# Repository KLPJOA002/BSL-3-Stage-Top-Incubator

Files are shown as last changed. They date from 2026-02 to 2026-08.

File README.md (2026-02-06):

# **Feasibility Study Around Designing a BSL-3 Compatible Stage Top Bio Containment System**
---
This repository contains the information relating to the investigation of commercial stage top incubation systems in order to determine the feasibility of designing a custom incubator system that provides the necesary environmental control and containment capibilities that allow it to be utilised within a BSL-3 laboratory.
This project extends to provide some conceptual containment designs that could be utiliesd for a prototpye capable of basic temperature control.

---
**Change Log:**
V1.0: 
1.  Chamber uses holes for bolts, base has hexagonal recesses for sitting the nut flush.
2.  Lid and Base use outwards facing notches for the insertion of viewing/illumination plates (Glass or aluminium).
3.  Base has a simple groove for an o-ring.

V2.0:
1.  Viewing/illumination plates notches moved to inside of chamber for better pressure sealing.
2.  Plate on base has been removed to reduce optical obstructions between objective and Multi-Well Plate.
3.  Multi-Well base used to seal the chamber. (Done with assumption of flat base)
4.  O-Ring Grooves for the lid designed to fit in V shaped groove in base, Oring sits in Lid.
5.  All O-ring sketches and extrusions made with parametric modeling.

V2.1: 
1.  Multi-Well model updated to include base frame (no longer flat bottom)
2.  Base seal with Multi-Well changed so that Multi-Well fram sits inside groove which will have gasket for seal.

V3.0:
1.  All corners are rounded for consideration with subtractive manufacturing.
2.  Inner chamber expanded for more internal space
3.  Size of chamber reduced.

V3.1:
1.  Minor Tweaks to dimensions

V3.2:
1.  Minor Tweaks to dimensions
   
V3.3:
1.  Inner chamber expanded furthur.
2.  V shape groove in base expanded for accomodation with 0.4mm 3D printer nozel
3.  Stand-offs added to lid to press the Multi-Well plate into the base.
4.  Holes for screws modified to allow for a hex socket screw with a head.

V3.4:
1.  Screws changed to be 7991 - Hexagon Socket Countersunk Screws (M4x10).
2.  Base screw hole modified to fit an insert for screw.

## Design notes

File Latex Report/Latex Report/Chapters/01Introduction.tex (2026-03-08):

% ----------------------------------------------------
% Introduction
% ----------------------------------------------------
\documentclass[class=report,11pt,crop=false]{standalone}
\input{../Style/ChapterStyle.tex}
\begin{document}
% ----------------------------------------------------
\chapter{Introduction} \label{ch:introduction}
\vspace{-1cm}
% ----------------------------------------------------

\section{Background and Summary}
Long term Live-Cell imaging is a very useful research tool when determining long term behavior of cell cultures in various situations. Commercial solutions are unable to provide adequate containment for the use within a Bio-Safety Level 3 (BSL-3) and often require the use of a separate containment enclosure, which introduces additional costs and complexity.

%This project focuses on the conceptual design of a low-cost Stage-Top Incubator that is capable of being utilized within a BSL-3 laboratory, without the requirement for additional containment. The primary focus with this project is specific suitability with Mycobacterium tuberculosis, however does consider other microbe requirements

This project focuses on the conceptual design of a bio-containment chamber which can be used within a BSL-3 lab to provide adequate containment for the long term observation of bacterial cultures. The main objective of this project is to allow long term observation of Mycobacterium tuberculosis (M. tb) grown in a multi-well plate.

This project is intended to provide an initial report on the feasibility of partaking in a further project to provide a complete incubation system for cell growth and observation.  

% =====================================================
\section{Scope and Limitations}
This project scope is limited to the following:
\begin{itemize}
	\item Preliminary Research
	\item Bio-Containment
	\item Compatibility with Multi-Well microtiter plates
	\item Primary containment of Mycobacterium tuberculosis (M. tb)
\end{itemize}

This project is limited to compatibility with a BSL-3 Lab and does not consider higher containment requirements. The chamber does not include any environmental control aspects and is limited to providing containment. The initial design is limited to compatibility with a Greiner 96 well microtiter plate. The use case of this project is limited to consider the requirements of M. tb

% =====================================================
\section{GitHub Link}
 The project documentation and container model files can be found at \url{https://github.com/KLPJOA002/BSL-3-Stage-Top-Incubator}
% ----------------------------------------------------
\ifstandalone
\bibliography{../Bibliography/References.bib}
\fi
\end{document}
% ----------------------------------------------------

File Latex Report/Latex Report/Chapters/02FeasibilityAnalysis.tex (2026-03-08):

% ----------------------------------------------------
% Requirements Analysis
% ----------------------------------------------------
\documentclass[class=report,11pt,crop=false]{standalone}
\input{../Style/ChapterStyle.tex}
\begin{document}
% ----------------------------------------------------
\chapter{Specification Analysis} \label{ch:FeasibAnalysis}
\vspace{-1cm}
% ----------------------------------------------------
% =====================================================
\section{Commercial Assessment}
The commercial solutions from Zeis/Pecon, Ibidi, Tokai-Hit and Okolab are assessed for their primary method of operation as well as the environmental control specifications provided by each product.

\subsection{Zeis/Pecon}
The incubation system provided by Zeis/Pecon utilises four modules for the control of the four major environmental conditions. A temperature unit for thermal control, a CO2 unit for CO2 concentration control, an O2 unit for O2 concentration control and a humidifying bottle for humidity control.

The heating unit monitors and controls the temperature of the culture sample through heating of the incubation chamber, gas airflow and humidifying bottle.

The CO2 unit monitors and controls the concentration of CO2 being pumped into the incubation chamber by controlling the release of pure CO2 gas into the internal mixing chamber.

The O2 unit monitors and controls the concentration of O2 being pumped into the incubation chamber by controlling the release of Pure N2 gas into the circulating gas in order to displace the O2 present. Thus can only achieve hypoxia conditions.

The humidifying unit operates by bubbling the gas mixture through heated water to achieve a close to 100\% RH ro prevent the drying of the culture media.

The Zeis/Pecon incubation system as a whole has the specifications shown in \autoref{tab:Zeis/Pecon_Specs}.

\begin{table}[H]
	\centering
	\begin{tabularx}{\textwidth}{|X|X|}
		\hline
		\textbf{Temperature Control Range} & Ambient - 60\degree C (Recommended max 45\degree C)                                                             \\ \hline
		\textbf{Control Accuracy}          & \textpm0.15\%                                                                                        \\ \hline
		\textbf{Control Resolution}        & \begin{tabular}[c]{@{}l@{}}Internal Loop: 0.01\degree C\\ User Parameter: 0.1\degree C\end{tabular}             \\ \hline
		\textbf{CO2 Control Range}         & 0.0 - 8.0 vol\% (8.1-10 vol\% with Uncepecified Reduced Accuracy)                             \\ \hline
		\textbf{Control Accuracy}          & \textpm2 vol\%                                                                                       \\ \hline
		\textbf{Control Resolution}        & \begin{tabular}[c]{@{}l@{}}Internal Loop: 0.01 vol\%\\ User Parameter: 0.1 vol\%\end{tabular} \\ \hline
		\textbf{O2 Control Range}          & 0.0 - 21.0 vol\%                                                                              \\ \hline
		\textbf{Control Accuracy}          & \textpm0.05 vol\%                                                                                    \\ \hline
		\textbf{Control Resolution}        & \begin{tabular}[c]{@{}l@{}}Internal Loop: 0.01 vol\%\\ User Parameter: 0.1 vol\%\end{tabular} \\ \hline
		\textbf{Operation}                 & PC or Suitable Microscope required                                                            \\ \hline
		\textbf{Compatibility}             & Petri-Dishes, Chambers, Chamber Plates, Chamber Slides, Multi-Well Plates                     \\ \hline
	\end{tabularx}
	\caption{Specifications for Zeis/Pecon Incubation System \cite{peconPeconZeisTempModule}, \cite{peconPeconZeisCO2}, \cite{peconPeconZeisO2}, \cite{peconPeconZeisHeating}}
	\label{tab:Zeis/Pecon_Specs}
\end{table}
\subsection{ibidi}
The incubation system provided by Ibidi utilises three modules to maintain the environmental conditions within in incubation chamber. A temperature unit for thermal control, a CO2/O2 unit for CO2 and O2 concentration control, and a humidifying column for humidity control.

The heating unit monitors and controls the temperature of the culture sample through heating of the incubation chamber.

The CO2/O2 unit monitors and controls the concentration of both CO2 and O2 being pumped into the incubation chamber by controlling the release of pure CO2 and N2 into the gas mixture. The release of N2 displaces oxygen present in the air and so the system is only capable of producing hypoxia conditions. The CO2/O2 unit is also responsible for the heating of the gas mixture as well as the heating of the humidifying column and gas tube.

The humidification control system works by controlling the mix of dry gas with humidified gas which is obtained through bubbling the dry gas flow through heated distilled water.

The Ibidi incubation system as a whole has the specifications shown in \autoref*{tab:Ibidi_Specs}.

\begin{table}[H]
	\centering
	\begin{tabularx}{\textwidth}{|X|X|}
		\hline
		\textbf{Temperature Control Range} & Ambient + 5\degree C - 50\degree C                                \\ \hline
		\textbf{Control Accuracy}          & \textpm 0.2\degree C with \textpm 0.5\degree C uniformity                         \\ \hline
		\textbf{Control Resolution}        & User Parameter: 0.1\degree C                             \\ \hline
		\textbf{CO2 Control Range}         & 0.0 - 15.0 vol\%                                \\ \hline
		\textbf{Control Accuracy}          & \textpm 0.2 vol\% + 3\% of Reading                      \\ \hline
		\textbf{Control Resolution}        & User Parameter: 0.1 vol\%                       \\ \hline
		\textbf{O2 Control Range}          & 0.5 - 21.0 vol\%                                \\ \hline
		\textbf{Control Accuracy}          & \textpm 0.2 vol\% (typical), \textpm 0.7 vol\% (max)            \\ \hline
		\textbf{Control Resolution}        & User Parameter: 0.1 vol\%                       \\ \hline
		\textbf{Humidity Control Range}    & Supply RH - 99\% RH                             \\ \hline
		\textbf{Sensor Accuracy}           & \textpm 2.5\%                                           \\ \hline
		\textbf{Control Resolution}        & 0.1\%                                           \\ \hline
		\textbf{Operation}                 & On Device Controls or Connected PC              \\ \hline
		\textbf{Compatibility}             & Petri-Dishes, Chamber Slides, Multi-Well Plates \\ \hline
	\end{tabularx}
	\caption{Specifications for Ibidi Incubation System \cite{ibidiIbidiHeatingSystem}, \cite{ibidiIbidiGasIncubation}}
	\label{tab:Ibidi_Specs}
\end{table}

\subsection{Tokai Hit}
The incubation system provided by Tokai hit utilises one or two modules to maintain the environmental conditions within the incubation chamber, depending on the parameters that are desired to be controlled. The STXG/STXF module is capable of regulating both temperature conditions and CO2 gas concentration. An additional unit, STX-CO2O2, can be connected to the system to override the gas mixture control, and provide control for CO2 and O2 concentration.

The STXG/STXF unit monitors and controls the temperature of the culture sample through heating of the incubation chamber. Additionally this unit is capable of regulating the concentration of CO2 being pumped into the incubation chamber. The STXG model can regulate the CO2 concentration by controlling the release of pure CO2 into the gas mixture, whereas the STXF module requires a pre-mixed pressurised air supply with 5\% CO2.

O2 concentration can be achieved using a separate optional module which provides full gas concentration control.

Humidity in the incubation chamber is controlled through a heated water bath that is situated inside the chamber, and so forces a constant high relative humidity.

The specifications for the STXG and STX-CO2O2 incubation system is shown in \autoref{tab:TokaiHit_Specs}.  
\begin{table}[H]
	\centering
	\begin{tabularx}{\textwidth}{|X|X|}
		\hline
		\textbf{Temperature Control Range} & Ambient +5\degree C - 65\degree C         \\ \hline
		\textbf{Control Accuracy}          & \textpm 0.3\degree C at heater surface    \\ \hline
		\textbf{Control Resolution}        & User Parameter 0.1\degree C               \\ \hline
		\textbf{CO2 Control Range}         & 5\% vol - 20\% vol                        \\ \hline
		\textbf{Control Accuracy}          & \textpm 0.1\% vol                         \\ \hline
		\textbf{Control Resolution}        & User Parameter 0.1\% vol                  \\ \hline
		\textbf{O2 Control Range}          & 0.1\% vol - 18\% vol                      \\ \hline
		\textbf{Control Accuracy}          & ---                                       \\ \hline
		\textbf{Control Resolution}        & ---                                       \\ \hline
		\textbf{Operation}                 & On Device or Connected PC                 \\ \hline
		\textbf{Compatibility}             & Petri-Dishes, Chamber Slides, Multi-Well Plates\\ \hline
	\end{tabularx}
	\caption{Specifications for the Tokai Hit Incubation System \cite{tokaihitSTXSeriesInstruction}}
	\label{tab:TokaiHit_Specs}
\end{table}

\subsection{OkoLab}
The incubation system provided by OkoLab utilises three modules to maintain the environmental conditions. A temperature unit for thermal control, a gas unit for CO2 and O2 concentration control and a humidifying bottle. 

The heating unit monitors and controls the temperature of the culture sample through heating of the incubation chamber.

The CO2/O2 unit monitors and controls the concentration of both CO2 and O2 being pumped into the incubation chamber. The gas module is capable of working with a mix of concentrated O2, concentrated CO2, and concentrated N2 to obtain a complete control of the gas mixture being passed into the incubation chamber. Alternatively, the unit can operate with a supply of pressurised air, concentrated N2 and concentrated CO2 to get less complete atmospheric control.

Humidity control is obtained by bubbling the gas mixture through heated water to increase the relative humidity.

The specifications for the OkoLab incubation system is shown in \autoref{tab:OkoLabs_Specs}

\begin{table}[H]
	\centering
	\begin{tabularx}{\textwidth}{|X|X|}
		\hline
		\textbf{Temperature Control Range} & Ambient +3\degree C - 60\degree C                                               \\ \hline
		\textbf{Control Accuracy}          & \textpm 0.1 for sample feedback, \textpm 0.3 for chamber feedback             \\ \hline
		\textbf{Control Resolution}        & User Parameter 0.1                                            \\ \hline
		\textbf{CO2 Control Range}         & 0\% vol - 20\% vol                                            \\ \hline
		\textbf{Control Accuracy}          & \textpm 0.2\% vol at 5\% vol                                          \\ \hline
		\textbf{Control Resolution}        & User Parameter 0.1\% vol                                      \\ \hline
		\textbf{O2 Control Range}          & 0\% vol - 95\% vol (using Pure O2 source, otherwise 20\% max) \\ \hline
		\textbf{Control Accuracy}          & \textpm 0.2\% at 5\% vol                                              \\ \hline
		\textbf{Control Resolution}        & User Parameter 0.1\% vol                                      \\ \hline
		\textbf{Humidity Control Range}    & 26\% RH - 95\% RH at 50                                       \\ \hline
		\textbf{Control Accuracy}          & \textpm 1\%                                                           \\ \hline
		\textbf{Control Resolution}        & User Parameter 1\%                                            \\ \hline
	\end{tabularx} 
	\caption{Specifications for the OkoLab Incubation System}
	\label{tab:OkoLabs_Specs}
\end{table}
% =====================================================
\section{Requirements}
The eventual goal of this project is the development of a stage top incubator that can be used for long term observations of M. tb within a BSL-3 without the requirement of a large external incubation and containment chamber.

However this report focuses on determining the feasibility of undertaking this project, and so has a reduced set of requirements aimed at scoping the fundamental aspects that would be required to understand the project scope.
Therefore the requirements for this project include the following:
\begin{itemize}
	\item Containment of Mycobacterium tuberculosis (M. tb)
	\item Compatibility with low magnification microscope stage
	\item Compatibility with a BSL-3 laboratory
	\item Compatibility with a 96-well culture vessel
\end{itemize}

This project focuses on the main aspect of bio-containment within a BSL-3 lab and how that can be achieved with a format that is compatible with the growth vessels and microscopy standards that are utilised for this kind of experiment.
\begin{comment}

\begin{table}[h]
    \centering
    \caption{User and functional requirements of the power subsystem.}    \label{tab:requirements}
    \begin{tabular}{|c|l|}
        \hline
        \textbf{ Requirement ID} & \textbf{Description} \\
        \hline
         UR01 & \\
         \hline
         FR01 & \\
         \hline
         &  \\
         \hline
         &  \\
         \hline
    \end{tabular}
\end{table}
\end{comment}

% =====================================================
\section{Specifications}

The commercial solutions were assessed to obtain an understanding of specifications the stage-top incubator project would need to meet in order to achieve a incubation system that would provide suitable conditions required for this type of long term imaging with cell cultures.

\autoref{tab:Derived_Specs} shows the list of specifications that were decided on based off the specifications for the commercial solutions shown above. These specifications fall within those provided by commercial solutions and should facilitate the incubation of most cell cultures.

\begin{table}[]
	\centering
	\begin{tabular}{|l|l|}
		\hline
		\textbf{Temperature Control Range} & Ambient - 55         \\ \hline
		\textbf{Temperature Accuracy}      & 0.2                  \\ \hline
		\textbf{Temperature Resolution}    & 0.1                  \\ \hlineB{5} 
		\textbf{CO2 Control Range}         & 0\% vol - 15\% vol   \\ \hline 
		\textbf{CO2 Control Accuracy}      & 0.1\% vol            \\ \hline
		\textbf{CO2 Control Resolution}    & 0.1\% vol            \\ \hlineB{5}
		\textbf{O2 Control Range}          & 0.5\% vol - 20\% vol \\ \hline
		\textbf{O2 Control Accuracy}       & 0.1\% vol            \\ \hline
		\textbf{O2 Control Resolution}     & 0.1\% vol            \\ \hlineB{5}
		\textbf{Humidity Control Range}    & 90\% RH - 99\%RH     \\ \hline
		\textbf{Humidity Control Accuracy} & ---                  \\ \hline
		\textbf{Humidity Control Range}    & ---                  \\ \hline
	\end{tabular}
	\caption{Derived Specifications for the Continuation of this Project.}
	\label{tab:Derived_Specs}
\end{table}
\begin{comment}
\begin{table}[h]
    \centering
    \caption{Specifications of the sensing subsystem derived from the requirements in \autoref{tab:requirements}.}    \label{tab:specifications}
    \begin{tabular}{|c|l|}
        \hline
        \textbf{Specification ID} & \textbf{Description} \\
        \hline
         SP01 & User \\
         \hline
         &  \\
         \hline
         &  \\
         \hline
    \end{tabular}
\end{table}
\end{comment}
% =====================================================
%\section{Feasibility}
%discus whether undertaking this project is feasible. 
% The table given below is an example of how you can present your ATPs. You are welcome to change or adapt it to your need. The example given is not a valid ATP description.

\begin{comment}
\begin{table}[h]
  \begin{center}
    \caption{Subsystem acceptance tests}
    \label{tab:tests}
    \begin{tabular}{| >{\centering\arraybackslash}m{1cm} | m{4cm}| m{5cm}| m{5cm}|}
      \hline
      \textbf{ID} & \textbf{Description} & \textbf{Testing Procedure}& \textbf{Pass/Fail Criteria} \\   
      \hline
      AT01 & Powers on & \tabitem \newline\indent\tabitem & \\
      \hline
       &  &\tabitem \newline\indent\tabitem  & \\
      \hline 
    \end{tabular}
  \end{center}
\end{table}

\end{comment}

% ----------------------------------------------------
\ifstandalone
\bibliography{../Bibliography/References.bib}
\fi
\end{document}
% ----------------------------------------------------

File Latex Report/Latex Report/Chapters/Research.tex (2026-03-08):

% ----------------------------------------------------
% Research
% ----------------------------------------------------
\documentclass[class=report,11pt,crop=false]{standalone}
\input{../Style/ChapterStyle.tex}
\begin{document}
	% ----------------------------------------------------
	\chapter{Research} \label{ch:Research}
	\vspace{-1cm}
	% ----------------------------------------------------
	%The conceptual design began with assessing existing commercial products to identify the key environmental control specifications required for the incubator to function correctly. Additionally, this was useful in identifying why the commercial products are incompatible with a BSL-3 lab when used without a separate external biological containment mechanism.
	
	The design process began by researching existing commercial products that provide stage-top incubation. This allows for the assessment of these commercial solutions to identify the methods of operation and the specifications that would be required for the possible design of a complete incubation system. Further this identifies the shortfalls that prevent the use of these products within BSL-3 laboratories as bio-containment chambers.
	
	\section{Zeis/Pecon}
	The Zeis/Pecon stage top incubator utilities four modules to control the environmental conditions within the incubator stage. 
	
	The Pecon Temperature Module S\cite{peconPeconZeisTempModule} regulates the temperature of the incubator. It has four 8-pin connectors that are used for temperature control of heated components such as the Incubator lid, incubator base, microscope objective and humidifier device. The temperature module is the base module for the entire incubation system, providing electrical power and communications to all connected devices. It directly connects to the CO2 module to provide power, communication and makes a connection to the gas circulation system to heat the gas flow provided to the incubation chamber. The temperature module requires an external device such as a PC or compatible microscope for operation as it does not have any control panel. The module maintains culture temperature by monitoring and controlling the temperature of the incubator base, lid and optionally the microscope objective. The module is capable of controlling the culture temperature using thermal pre-sets, or by performing a pre-experiment calibration whereby an identical set-up is placed in the chamber with the included culture temperature sensor to tune the required chamber temperatures. 
	
	The Pecon CO2 Module S\cite{peconPeconZeisCO2} attaches to the temperature module for electrical power and communication, and provides CO2 concentration control to the airflow passed into the incubation chamber. The CO2 module circulates gas throughout all the connected units and mixes the gas before pumping the resultant mixture into the incubation chamber. The module contains a CO2 sensor which monitors the concentration of CO2 in the gas mixture, and controls the release of pure CO2 into the mixing chamber in order to maintain the desired CO2 concentration. Due to the method of operation, it requires a >95\% purity CO2 supply.
	
	The Pecon O2 Module S\cite{peconPeconZeisO2} attaches to the CO2 module for electrical power and communication. This module functions similarly to the CO2 module, however it regulates the concentration of O2 present in the gas mixture by controlling the release of a pure N2 supply into the air mixture to displace the O2 present. This method of O2 displacements means that the O2 module is only capable of providing hypoxia conditions by lowering O2 concentration. Due to the method of operation, it requires a >99\% purity N2 supply.
	
	%The Pecon Heating Device Humidity S\cite{pecon_peconzeis_nodate-3} connects in series with the airflow tube to the incubator stage. This module works by bubbling the airflow through heated sterile water in order to raise the relative humidity (RH) to approximately 100\%.
	
	Both the CO2 module and O2 module are supplied with a humidifying bottle which functions by bubbling the the gas airflow thorugh distilled water to raise the relative humidity (RH). The Pecon Heating Device Humidity S1\cite{peconPeconZeisHeating} is an optional module which connects to the Temperature module to heat the humidifying bottle to increase the RH and maintain adequete gas temperature provided to the incubation chamber
	
	The incubator stage includes a heated glass topped lid\cite{peconIncubatorS1Compact} and a heated insert which accepts mounts for the different culture vessels used in microscopy. The heated insert directly heats the culture medium through physical contact, and the heated lid provides radiative heating and condensation prevention by heating the glass panel directly. The insert supports perfusion experiments utilising two ports which allow tubes to be run to the culture.
	
	%The main reason why the Zeis/Pecon stage top incubator system is not suitable for long term imaging without an external containment enclosure is due to the method of gas flow through the incubator. The design of the Incubator stage is such that the inflowing gas mixture flows over the culture media and then exhausts passively through the opening on the bottom and through the sides. This means that the cell culture is not completely sealed inside the incubator which can result in contamination. The incubator lid and heated insert are not autoclabale and this reduces the sterilisation capibilities of the incubation chamber.
	
	\section{Ibidi}
	The Ibidi stage top incubator functions similarly to the Zeis/Pecon module, however it makes use of three modules to maintain environmental conditions.
	
	The Heating System Silver Line\cite{ibidiIbidiHeatingSystem} module regulates the temperature of the incubator. It makes use of 6 independent channels connected via 4 ports, two of which connect to two channels each. These channels are used to monitor and control the temperature of the components used in the system, such as the heated lid and heated plate. The module maintains culture temperature by monitoring and controlling the temperature of the heated lid, heated base and optionally the microscope objective. The module infers the culture temperature using pre-set temperatures, or by performing a calibration whereby an identical set-up is placed in the chamber with the included thermocouple to tune the required chamber settings to meet the desired culture temperature. The temperature module can be operated using the on device buttons and screen, or it can be connected to a PC for control using the free software. The temperature module does not heat the gas mixture.
	
	The Gas Incubation System\cite{ibidiIbidiGasIncubation} comes in two different models, the CO2 - Silver Line and the CO2/O2 - Silver Line. The difference between these two systems is the former is only capable of regulating CO2 concentration, where as the latter has the ability to regulate O2 concentration as well as CO2 concentration. The module has three gas inputs for pressurised air, CO2 and N2. The CO2 and N2 are fed into and mixed with the pressurised air to obtain a mixture with the desired CO2 and O2 concentrations. The module then heats the gas mixture before pumping it to the incubation chamber. If the CO2 only module is used, the N2 air input is still present on the device, however it is sealed internally and so the module is unable to regulate O2 concentration. Due to the method of using N2 to displace O2 in the mixture, this system is only capable of producing hypoxia environments. The gas incubator module has two output ports which are used in conjunction with the Humidifying column to mix the dry gas with humidified gas to obtain the desired relative humidity as shown in \autoref{fig:ibidiHumidityControlDiagram}. The gas incubation module has two electrical connections, one to control the heating of the humidifying column and gas line, and the second to connect to the humidity sensor present in the incubation chamber. The module can be operated using the on device buttons and screen, or it can be connected to a PC for control using the free software.
	
	The Humidifying column\cite{ibidiIbidiGasIncubation} works by bubbling the airflow through heated, distilled water to increase the relative humidity to approximately 100\% RH. This is then mixed with dry gas to obtain the desired \% RH.
	
	The Ibidi incubation chamber comes in two versions, one version supports culture mediums with Petri dishes and slides, the second version supports multi-well plates. The Petri dish/Slide version of the chamber supports perfusion experiments using two ports which allow tubes to be run to the culture. Both chambers directly heat the culture medium through physical contact and provide radiative heating and condensation prevention by heating the glass lid.

	\begin{figure}
		\centering
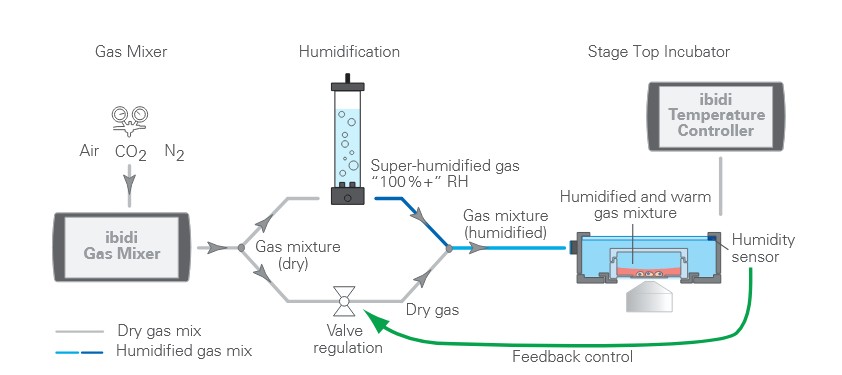
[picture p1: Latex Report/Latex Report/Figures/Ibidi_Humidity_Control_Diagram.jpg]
		
		\caption[Ibidi Chamber Gas Flow Diagram]{Diagram Showing the Humidity Control Mechanism Used by the Ibidi Gas Incubation System \cite{ibidiIbidiGasIncubation}}
		\label{fig:ibidiHumidityControlDiagram}
	\end{figure}
	
	\section{Tokai-Hit}
	The Tokai-Hit system functions similarly to the Pecon and Ibidi systems however it utilises a single module to regulate the environmental conditions for temperature and CO2. Humidity is controlled by a heated water bath inside the chamber, and O2 control is achieved by utilising an optional module which then overrides all gas control.
	
	The Tokai-Hit STXG/STXF\cite{tokaihitSTXSeriesInstruction} temperature and CO2 controller regulates both temperature and CO2 concentration in the incubation chamber. The controller utilises a single connector to control all component temperatures such as the Lid heater, bath heater, stage heater and optional microscope objective heater. The module can regulate thermal conditions of the culture using pre-set temperatures, however it can operate in feedback mode whereby a sensor directly monitors the temperature of the culture medium and automatically adjusts the component temperatures to meet the desired set point. The module can be operated using the built in touch screen or it can be connected to a PC for control using software.
	
	The STXG and STXF models both provide airflow to the incubation chamber, however the STXG model is capable of controlling the CO2 concentration by feeding supplied CO2 into the gas mixture until the desired concentration is reached, then pumps the mixture to the incubation chamber. The STXF model is unable to regulate CO2 concentration, and so requires a pre-mixed pressurised CO2/air.

	The incubator chamber uses a single design that is compatible with most major culture vessels including Petri dishes, slides and multi-well plates. This chamber supports perfusion experiments, drug administration and direct culture temperature measurement via access ports designed into the lid. The humidity inside the incubation chamber is maintained via a water bath that is present inside the chamber, and which is heated by the STXG/STXF module.
	
	The STXG/STXF modules can optionally be connected to a separate CO2/O2 unit which overrides the gas control mixture and allows for the optional control of O2 concentration.

	\section{OkoLab}
	The OkoLab utilises three modules to regulate environmental conditions within the incubation chamber
	
	The OkoLab H301-T-UNIT-BL-PLUS\cite{oko-labH301TUNITBLPLUS_Manual} unit is responsible for maintaining the thermal conditions within the chamber enclosure. It operates by monitoring and controlling the temperature of the chamber base, lid and optionally the microscope objective. This in turn heats the sample to the desired temperature. This heating unit is capable of sample temperature feedback utilising a thin thermocouple that can be placed in distilled water near the sample to obtain more accurate sample temperature control. Otherwise the unit is capable of using pre-sets/calibrations to infer sample temperature based on enclosure temperatures. The heating unit can be operated via a computer using available software or using optional touch screen accessory. The heating unit is capable of interfacing with the Oko-Lab Bold Line Gas Controllers. The temperature module supports a programmed temperature cycle mode where it cycles between set temperatures.

	The CO2-O2-UNIT-BL\cite{oko-labCO2O2UNITBL020_195_Manual} modules come in a variety of formats, differing in the O2 control ranges they support. The CO2-O2-UNIT-BL [0-20; 1-95] variant supports O2 concentration range from 1\% to 95\%. This model requires a pressurised supply of CO2, N2 and O2 to obtain the desired gas mixture, alternatively compressed air or an air pump can be connected to the N2 supply which limits the functionality to just CO2 concentration control. The CO2-O2 BL line all have the capability to directly interface with the Temperature unit to allow communication between the two units.
	
	The HM-ACTIVE\cite{oko-labHMACTIVE_Manual} operates by passing the gas mixture over heated water to increase the RH. The water temperature can be altered to control the RH of the out flowing gas. The humidity control unit is controlled by the gas mixture unit.
	
	The H301-K-FRAME\cite{oko-labH301KFRAME_User_Manual} uses a design that is compatible with most major culture vessels, each using a different sample holder. The chamber is also designed to work with various lids depending on the required application. The chamber supports perfusion experiments and microfluidic experiments. The chamber directly heats the culture medium through physical contact and provides radiative heating and condensation prevention by heating the glass lid

	\section{Shortfalls}
	
	\subsection{Containment}
	The commercial solutions provided by Zeis/Pecon, ibidi, Tokai Hit and OkoLab are all unable to operate independently, without an external containment chamber, within a BSL-3 laboratory due to a fundamental design choice present in all solutions. The Incubation chambers are designed to have an imperfect containment seal to allow the incoming gas flows to passively exhaust out the base and any gaps in the enclosure. This can be seen in the diagram shown in \autoref{fig:ibidigasflowdiagram} which is provided by ibidi.
	
	This means that the exhausting air is unfiltered and may be contaminated with the cells present during the experiment, which can lead to contamination of the surrounding workspace. For this reason, when working with potentially lethal pathogens, it is required that the incubator be placed within a larger containment vessel to ensure that contamination does not occur.
	
	\subsection{Disinfection and sterilisation}
	
	All equipment inside of a BSL-3 lab requires either sterilisation or disinfection depending on the equipment use or properties. Sterilisation is used to kill almost all micro cellular activity on an item and is rated on the Sterility Assurance Level (SAL) which indicates the probability of a single microbe surviving. Disinfection is used to kill enough micro cellular life to achieve a safe enough level required by the laboratory.
	Examples of sterilisation and disinfection techniques are as follows:
	
	\begin{itemize}
		\item Sodium hypochlorite(bleach), is useful as a broad spectrum disinfectant and is effective against bacterial spores\cite{BiologicalSafetyManual2021}, \cite{BiosafetyManualAppendixIDisinfectantsforBiohazardousMaterialsSOP}, \cite{barryBSL3LabDecontamination2025}. 
		
		\item hydrogen peroxide, which is a very effective sterilising chemical\cite{BiologicalSafetyManual2021} and is often used for sterilisation of tools, biological safety cabinets and laboratories\cite{grareEfficacyDryMist2008}.
		
		\item Quaternary Ammonium Compounds, which provides cost effective but low level disinfection\cite{BiologicalSafetyManual2021}, \cite{BiosafetyManualAppendixIDisinfectantsforBiohazardousMaterialsSOP}, \cite{barryBSL3LabDecontamination2025}.
		
		\item Alcohols, which offer an intermediary disinfection \cite{BiologicalSafetyManual2021}, however are ineffective against spores\cite{BiosafetyManualAppendixIDisinfectantsforBiohazardousMaterialsSOP}
		
		\item Autoclave, which provides extremely effective sterilization using a pressurized containment vessel filled with steam heated to approximately \(120^\circ\)C 
	\end{itemize}
	
	The aforementioned commercial solutions specify the use of concentrated  alcohol solutions such as ethanol or isopropanol, which are not suitable for adequate sterilisation of microbes which produce spores, such as Mycobacterium tuberculosis, which is the primary cell considered in this feasibility study.
	
	Furthermore the Tokai hit and Zeis/Pecon incubators specify that they are not compatible with autoclave sterilisation, whilst the Ibidi and OkoLab incubators do not specify any compatibility or incompatibility.
	\subsection{Key Takeaways}
	The discussed commercial solutions are incompatible with experiments that require stage top incubation for stand alone, long term, live cell imaging within a BSL-3 lab. This is because of the lack of adequate containment capabilities as well as the incompatibility with disinfection and sterilisation methods required by the microbes of interest.
	
	\begin{figure}
		\centering
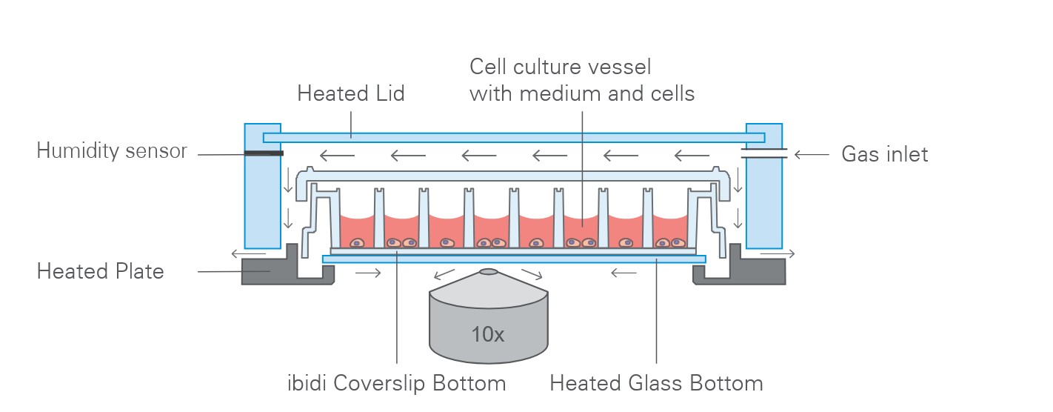
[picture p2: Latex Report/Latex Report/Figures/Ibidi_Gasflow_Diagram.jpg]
		
		\caption{Diagram Showing the Gas Flow within the ibidi Multi-Well Incubation Chamber}
		\label{fig:ibidigasflowdiagram}
	\end{figure}
	
	% ----------------------------------------------------
	\ifstandalone
	\bibliography{../Bibliography/References.bib}
	\fi
\end{document}
% ----------------------------------------------------

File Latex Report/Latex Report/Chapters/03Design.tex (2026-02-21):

% ----------------------------------------------------
% Subsystem Design
% ----------------------------------------------------
\documentclass[class=report,11pt,crop=false]{standalone}
\input{../Style/ChapterStyle.tex}
\begin{document}
% ----------------------------------------------------
\chapter{Conceptual Design} \label{ch:design}
\vspace{-1cm}
% =====================================================
The main focus on this report is centred about achieving a bio-containment system that allows for observing cultures grown in a 96-well plate. The system must ensure that no contamination can occur from the cells grown inside the container.

This section aims to describes the steps and decisions taken in the process of making a conceptual design for a containment vessel that meets the requirements mentioned in \autoref*{ch:FeasibAnalysis}. This conceptual design will help to determine the feasibility of taking this project further and incorporating incubation techniques which will enable the bio-containment vessel to be utilised as an incubation chamber that can be used for long term experimentation independently from traditional laboratory incubation cabinets

\section{Design Iterations}
\subsection{Design Version 1}

\begin{figure}
	\centering
	\begin{subfigure}[b]{0.45\textwidth}
		\centering
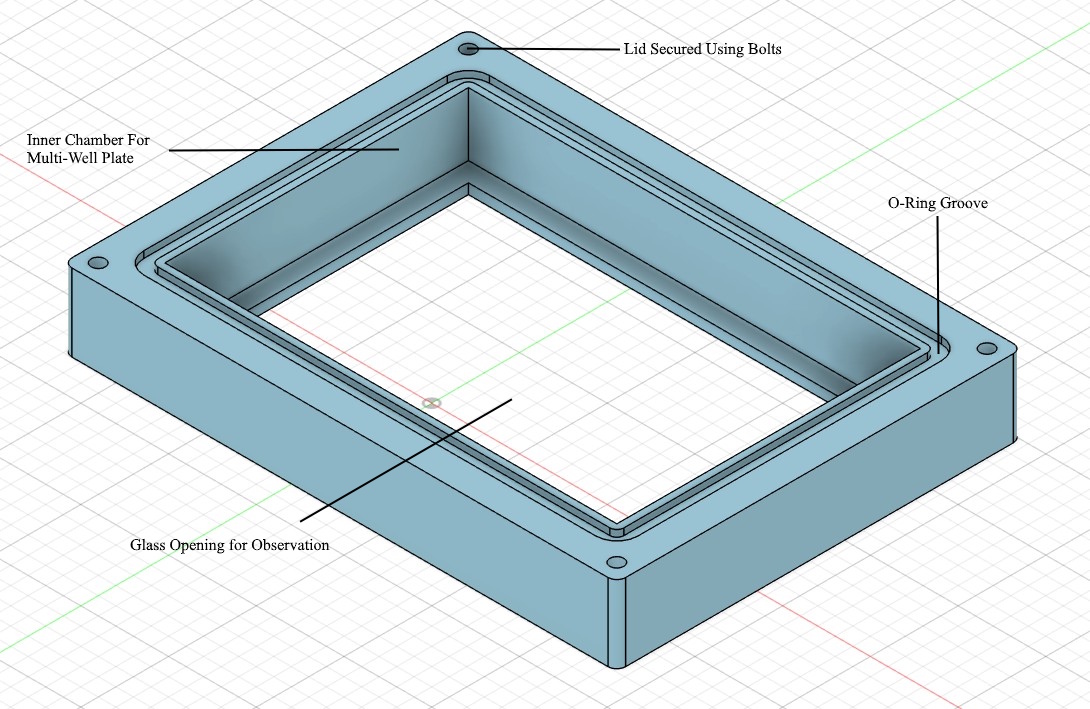
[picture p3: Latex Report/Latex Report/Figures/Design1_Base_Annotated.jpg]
		
		\caption[]{Conceptual Design 1 Base Top-Side}
		\label{fig:design1baseTop}
	\end{subfigure}
	\hfill
	\begin{subfigure}[b]{0.45\textwidth}
		\centering
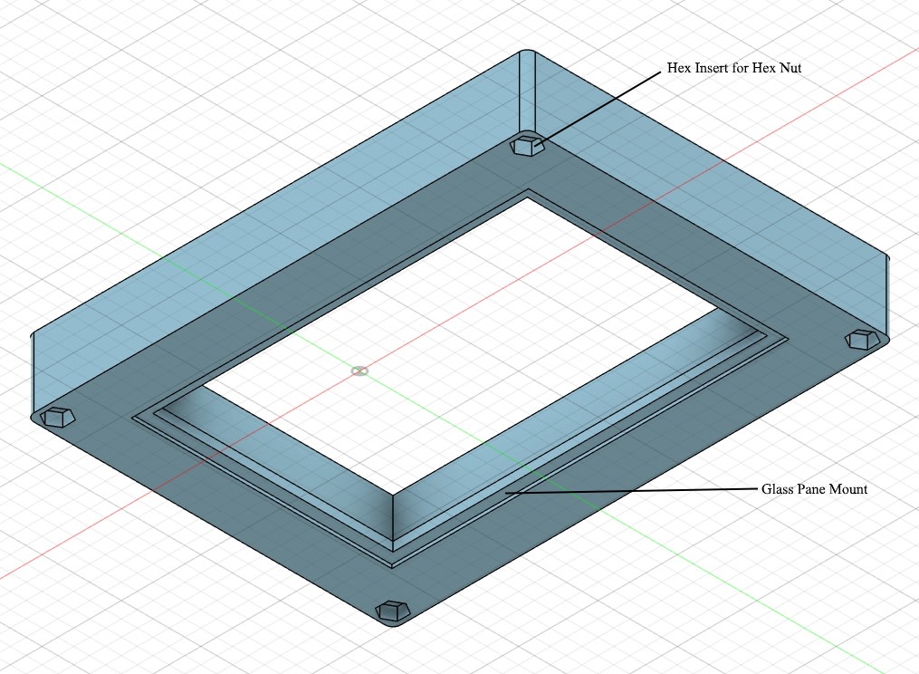
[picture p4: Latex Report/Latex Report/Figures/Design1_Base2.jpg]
		
		\caption[]{Conceptual Design 1 Base Bottom-Side}
		\label{fig:design1baseBottom}
	\end{subfigure}
	\caption[]{Conceptual Design 1 Base}
	\label{fig:design1Base}
\end{figure}

\begin{figure}
	\centering
	\begin{subfigure}[b]{0.45\textwidth}
		\centering
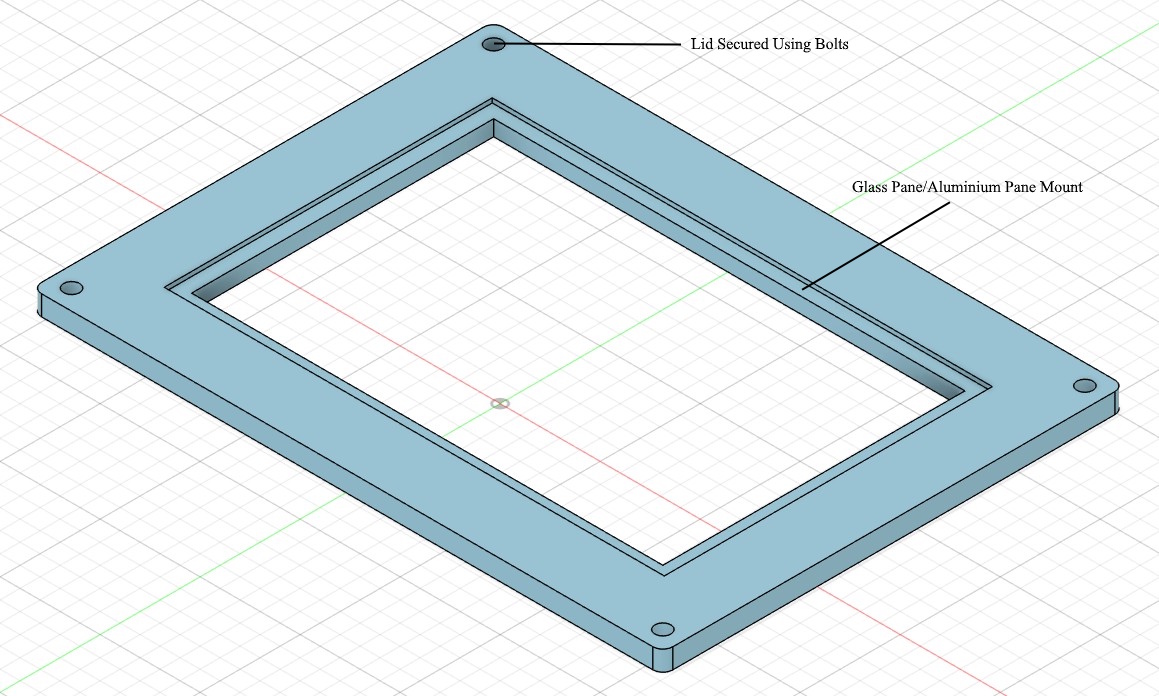
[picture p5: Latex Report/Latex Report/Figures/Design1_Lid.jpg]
		
		\caption[]{Conceptual Design 1 Lid Top-Side}
		\label{fig:design1LidTop}
	\end{subfigure}
	\hfill
	\begin{subfigure}[b]{0.45\textwidth}
		\centering
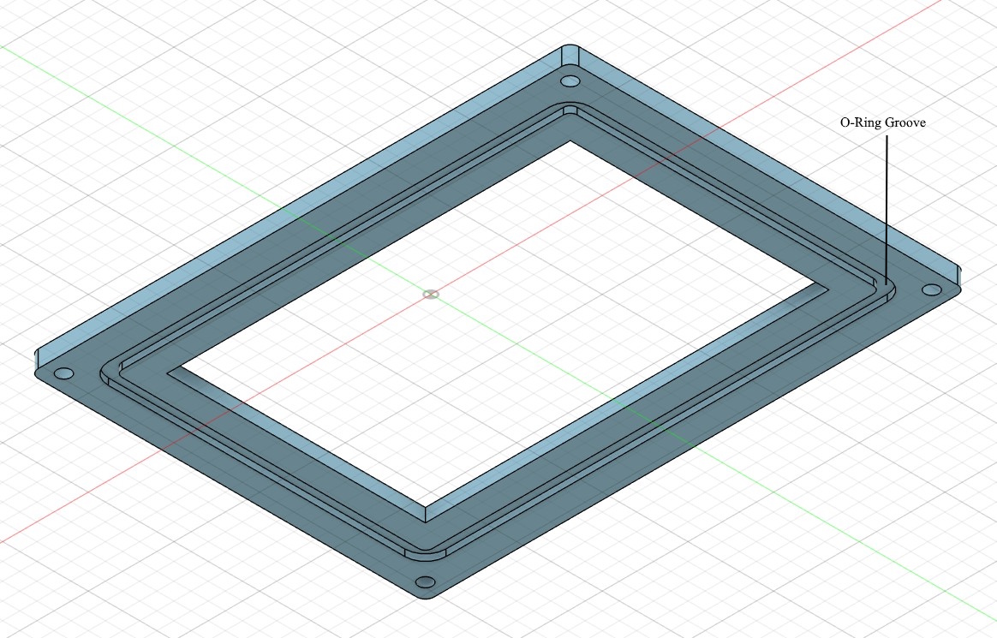
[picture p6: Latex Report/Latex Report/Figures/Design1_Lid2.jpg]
		
		\caption[]{Conceptual Design 1 Lid Bottom-Side}
		\label{fig:design1LidBottom}
	\end{subfigure}
	\caption[]{Conceptual Design 1 Lid}
	\label{fig:design1Lid}
\end{figure}

The first design version uses a base and a lid to seal the multi-well plate inside the chamber. 

%The base has a inner chamber that the multi-well plate is placed in. The plate rests on a ledge along the bottom of the base. The base has an opening on the bottom, which is designed such that a glass pane can be inserted and glued into place to allow for a complete seal whilst still allowing for a clear optical path for observation.

As can be seen in \autoref{fig:design1baseTop}, the base of the chamber has a internal cavity, which allows a multi-well plate to be placed inside, the plate is designed to rest on a ledge along the bottom of the inner cavity. There is a groove along the top which is designed to align with a groove in the lid shown in \autoref{fig:design1LidBottom}, and house an O-Ring which will seal the inner chamber. The base is designed to mount with the lid with the use of four M4 bolts which will run through the four holes in the corners of the base and lid.

\autoref{fig:design1baseBottom} shows the recess which is designed to allow a glass plate to be embedded into the base and sealed using epoxy or glue. This allows for a clear optical path for viewing the growth culture. The base also includes hex shaped recesses which allows for embedding a hex nut to interface with the M4 bolts used to mount the lid.

As shown in \autoref{fig:design1LidTop}, there is a similar recess which is designed to allow a glass plate or aluminium plate to be embedded into the lid sealed using epoxy or glue. A glass plate can be used to allow for a complete optical path from the top to bottom of the chamber, alternatively an aluminium plate can be embedded into the lid, this plate would utilise LED's and a heating element to provide better heating capabilities, as well as allowing the chamber itself to provide the required illumination required for microscopy.

\subsubsection{Changes}
This design was improved upon using the following alterations.

The recess for the glass/aluminium pane on the lid was moved from the outside of the lid to the inside of the lid. By making this change, any potential pressure within the container will press the pane into the lid and ensure the seal.

The design for a glass pane on the base of the container was removed and the frame of the multi-well plate was used as the sealing agent for the base of the container. By removing this pane on the base, there is a reduction in the chance of condensation forming on the pane which may obscure observation. Additionally, this allows the floor of the base to be thinner, which allows the multi-well plate to sit closer to the microscope objective and will allow for better observation.

The O-ring groove was altered to use a mating feature that allows the lid to mate with the base to ensure that there is proper alignment of the two parts. Additionally the O-ring would rest in this feature and utilise a standard O-ring groove design.  

\subsection{Design Version 2}
\begin{figure}
	\centering
	\begin{subfigure}[b]{0.45\textwidth}
		\centering
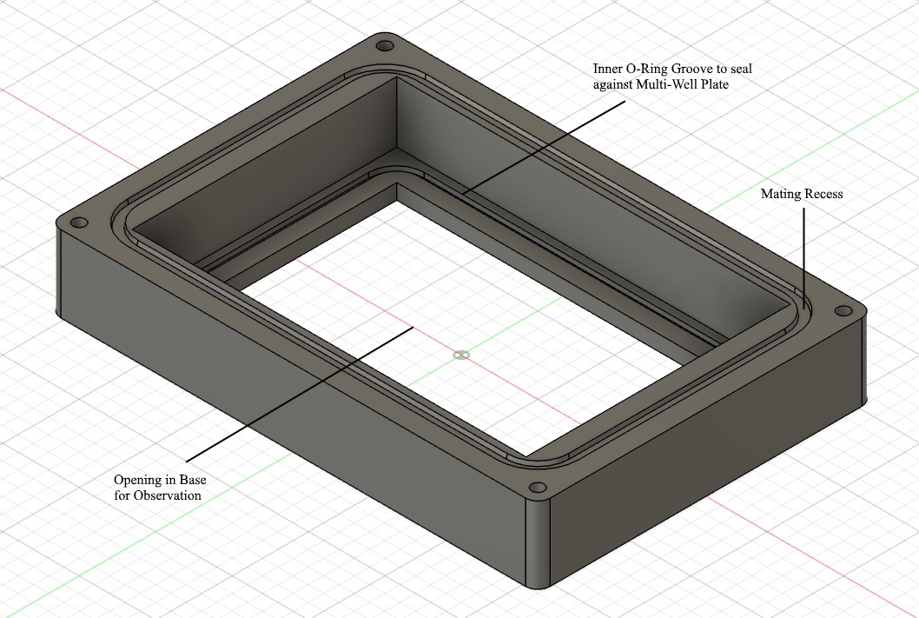
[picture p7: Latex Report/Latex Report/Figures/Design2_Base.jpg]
		
		\caption[]{Conceptual Design 2 Base}
		\label{fig:design2base}
	\end{subfigure}
	\hfill
	\begin{subfigure}[b]{0.45\textwidth}
		\centering
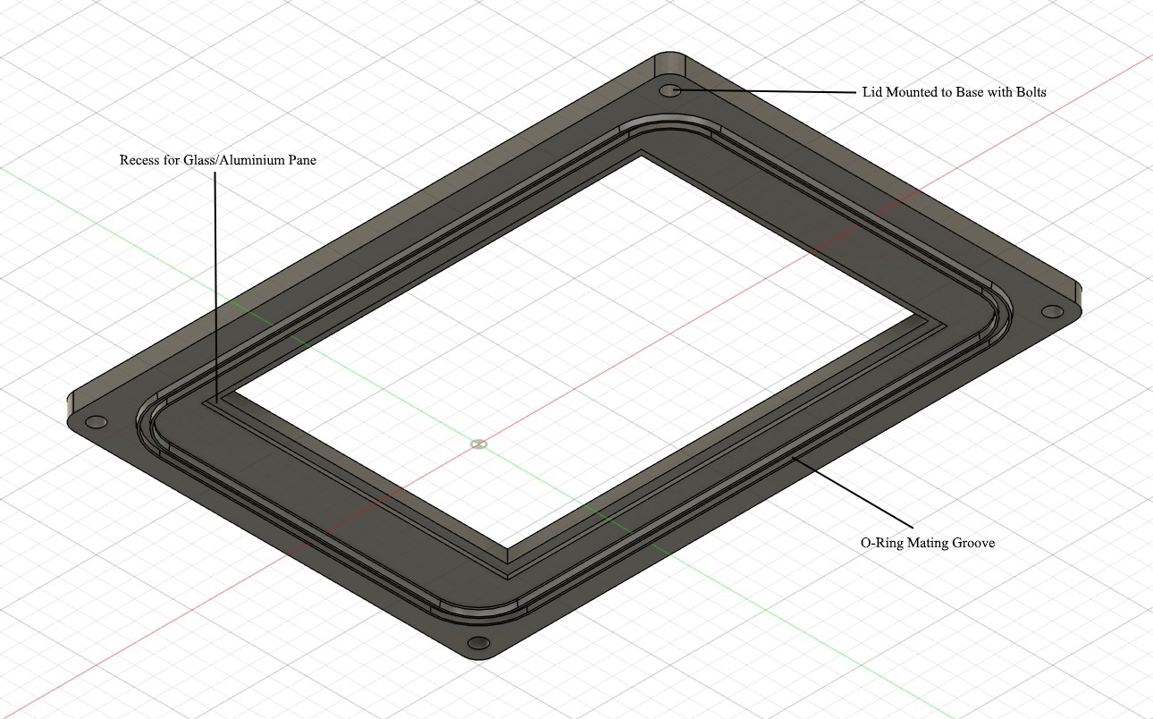
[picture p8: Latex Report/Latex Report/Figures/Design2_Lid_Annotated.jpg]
		
		\caption[]{Conceptual Design 2 Lid}
		\label{fig:design2Lid}
	\end{subfigure}
	\caption[]{Conceptual Design 2}
	\label{fig:design2}
\end{figure}

\begin{figure}
	\centering
	\begin{subfigure}[b]{0.45\textwidth}
		\centering
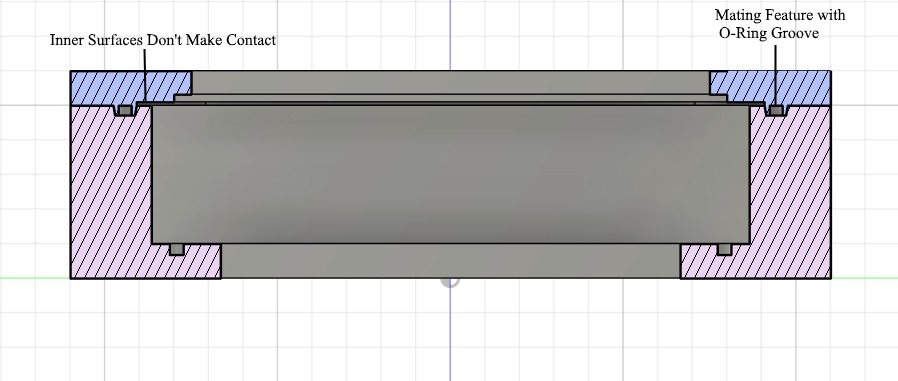
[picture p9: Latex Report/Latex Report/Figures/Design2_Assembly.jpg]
		
		\caption{Cross Section of Conceptual Design 2 Assembly}
		\label{fig:design2assembly}
	\end{subfigure}
	\hfill
	\begin{subfigure}[b]{0.45\textwidth}
		\centering
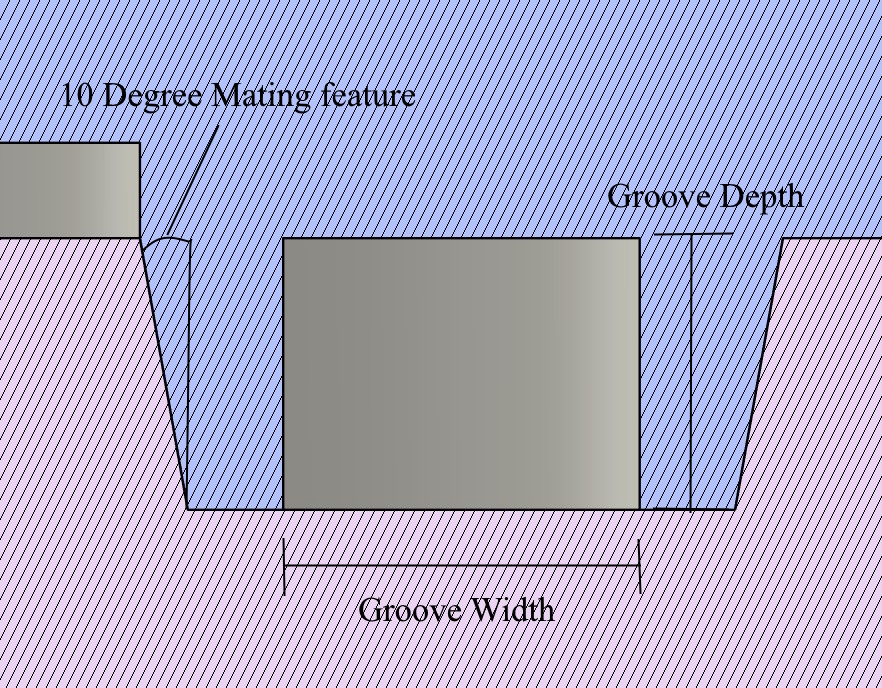
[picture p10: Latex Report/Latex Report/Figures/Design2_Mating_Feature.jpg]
		
		\caption{Design 2 Mating Featue and O-ring Groove}
		\label{fig:design2matingfeature}
	\end{subfigure}
\end{figure}

The fundamental design for the second version of the conceptual design is similar to that in version one. The chamber uses a base with a detachable lid to seal the multi-well plate inside the container. Two o-rings are used to seal the chamber and prevent contamination.

\subsubsection{O-Ring}

As can be seen in \autoref{fig:design2}, \autoref{fig:design2assembly} and \autoref{fig:design2matingfeature}, this updated version uses a mating feature where the base incorporates a recessed groove which will interface with the extruded feature on the lid. This ensures that the lid and base align correctly to provide a better seal. 

The groove for the o-ring was designed into the mating feature to ensure that the o-ring makes consistent contact with the intended sealing surface, which will be within the recess present on the base.

The base and lid feature a parametric design model, where the parameters of the o-ring to be used can be entered and the mating feature and o-ring groove will dynamically change to suit the given parameters

The total perimeter of the feature is determined by the circumference of the o-ring. The circumference of the o-ring is approximated by using \autoref{eqn:ORing_Circum}

\begin{equation}
	Circumfrence=2\pi(\frac{Oring_{ID}}{2}+\frac{Oring_{OD}}{2})
	\label{eqn:ORing_Circum}
\end{equation}

Based on this circumference, the O-ring groove is changed such that the it maintains the same rectangular ratio as the chamber itself, whilst changing the total mid-point perimeter such that the o-ring is not stretched when placed inside the groove.

The groove itself is designed according to recommendations and guides provided by the Parker Handbook \cite{ORingHandbook} and online articles including O-Ring Groove (Gland) Design Guide by Tessa Axsom \cite{axsomORingGrooveGland2022}. The width of the o-ring groove is designed to allow for a 5\% expansion in the o-ring diameter \cite{axsomORingGrooveGland2022}, this will ensure that the o-ring gets sufficiently compressed by the walls to ensure a suitable seal. According to the guides provided by Marco sealing solutions \cite{UnderstandingORingSqueeze} and Tessa Axosm \cite{axsomORingGrooveGland2022}, in order to obtain a suitable sealing effect, a static face seal must use an o-ring with a compression ration of between 20\% and 30\%. 

\begin{equation}
	CompressionRatio = \frac{ORing_{Diameter}-GrooveDepth}{ORing_{Diameter}}
	\label{eqn:OringCompression}
\end{equation}

\begin{equation}
	GrooveDepth = ORing_{Diameter}(1-CompressionRatio)
	\label{eqn:OringDepth}
\end{equation}

The equation for the compression ratio of an o-ring shown in \autoref{eqn:OringCompression} can be re-arranged into \autoref{eqn:OringDepth} to find the groove depth that is required to achieve the desired compression ratio for a given o-ring diameter. For this conceptual design, a compression ratio of 20\% was chosen as this would allow for a sufficient seal whilst still not preventing the lid to sit flush with the base

Since the containment chamber is designed with a rectangular profile, the corners of the o-ring groove need to utilise a fillet to prevent the the o-ring from being overstressed at the corners. According to the Parker O-Ring Handbook ORD-5700 \cite{ParkerORingHandbook}, the recommended inside corner radius should ideally be six times the cross sectional diameter of the o-ring, with a minimum of three times the cross sectional diameter. Therefore the container is designed to feature a fillet with a radius of six times the user defined o-ring cross-sectional diameter.

To ensure that the lid is self-locating with respect to the base, the mating feature is designed to have a 10\degree slope which will ensure that the lid is properly aligned with the base. Additionally as can be seen in \autoref{fig:design2assembly} and \autoref{fig:design2matingfeature}, the lid is designed to sit flush against the base outside of the seal, whilst the lid does not make contact with the base on the inside of the seal. This ensures that the lid sits flush with the base and does not sit unevenly on the base. 

\subsubsection{Base}
The base uses the same principle where the multi-well plate rests on a ledge that is present on the bottom of the base. The secondary o-ring groove is designed using the same methodology showed above. This was done using the premise that the multi-well plate features a flat base which can be pressed into the o-ring to provide a seal. 

The recess for a glass plate on the base was removed to eliminate the chance that condensation could form between this bottom plate and the multi-well plate which would obstruct the optical observations. 

The base is still designed to attach to the lid with the use of four M4 bolts that go through holes on the four corners. To avoid the potential difficulty of 3D printing an overhanging feature for the prototype, the hexagonal shaped recess on the bottom of the plate has been removed.

\subsubsection{Lid}
The lid features a recessed groove that allows for a glass or aluminium pane to be embedded into the lid. The recess was moved from the outside to the inside of the lid to ensure that any pressure formed within the chamber would ensure a that the seal is maintained.

\subsubsection{Changes}
Upon reviewing the second iteration of the design, the following choices were made to base the third iteration on.

Any sharp 90\degree corners were changed to feature rounded corners which better meets the capabilities of subtractive manufacturing techniques such as CNC milling. Additionally, most BSL-3 container practices avoid corners such as these as they are difficult to thoroughly disinfect and so often promote contamination.

The bottom seal is changed to better interface with the multi-well plate as the initial design went under the assumption that the bottom of the multi-well plate featured a flat base. The multi-well plate, the Greiner 96 Well Micro-plates, used in the laboratory does not follow this assumption. 

The holes used to secure the lid to the base are modified to ensure that the fastener is flush with the container to ensure that any features do not protrude outside the container. The M4 hex bolts are changed such that a threaded insert.

\section{Design Version 3}

\begin{figure}
	\centering
	\begin{subfigure}[b]{0.45\textwidth}
		\centering
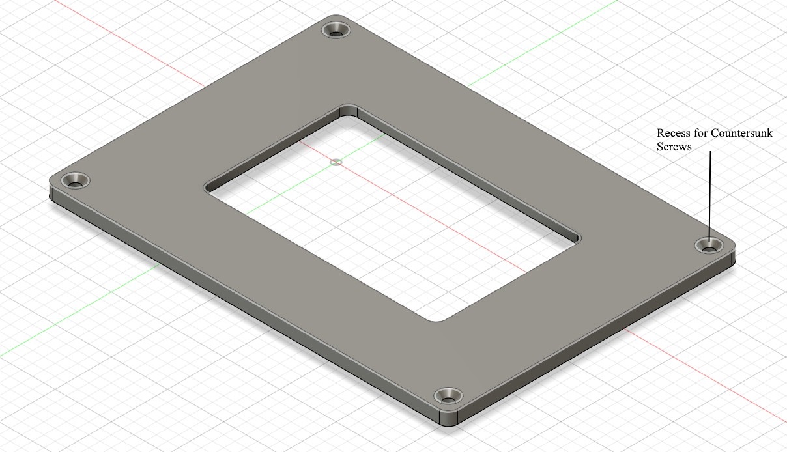
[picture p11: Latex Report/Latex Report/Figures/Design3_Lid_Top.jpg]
		
		\caption[]{Conceptual Design 3 Lid Topside}
		\label{fig:design3Lid_Top}
	\end{subfigure}
	\hfill
	\begin{subfigure}[b]{0.45\textwidth}
		\centering
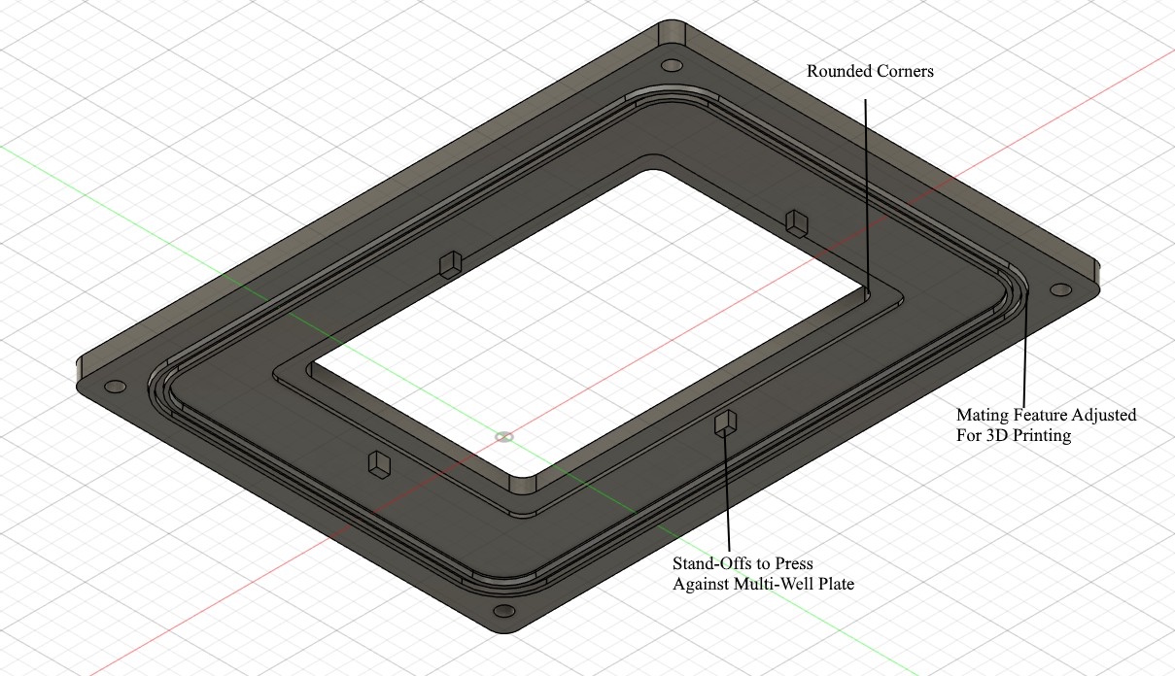
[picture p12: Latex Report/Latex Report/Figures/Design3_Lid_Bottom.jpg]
		
		\caption[]{Conceptual Design 3 Lid Bottom}
		\label{fig:design3Lid_Bottom}
	\end{subfigure}
	\caption[]{Conceptual Design 3 Lid}
	\label{fig:design3}
\end{figure}

\begin{figure}
	\centering
	\begin{subfigure}[b]{0.45\textwidth}
		\centering
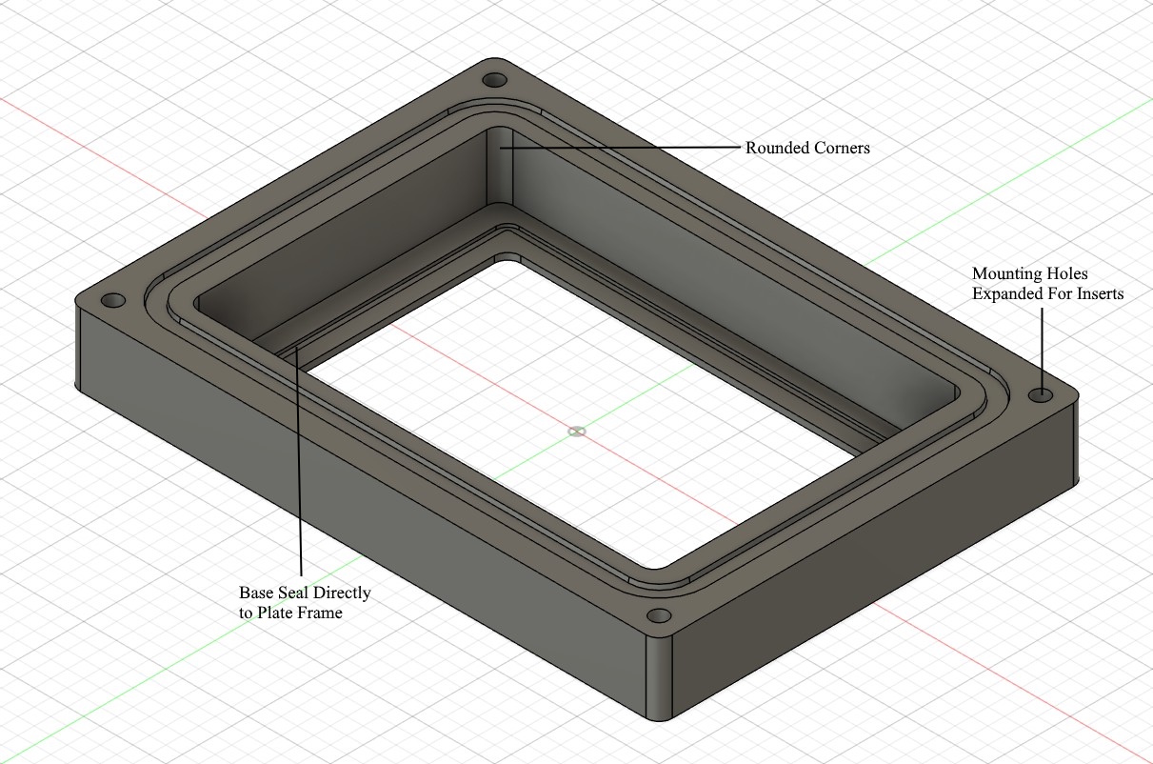
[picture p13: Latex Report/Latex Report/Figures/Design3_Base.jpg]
		
		\caption[]{Conceptual Design 3 Base}
		\label{fig:design3base}
	\end{subfigure}
	\hfill
	\begin{subfigure}[b]{0.45\textwidth}
		\centering
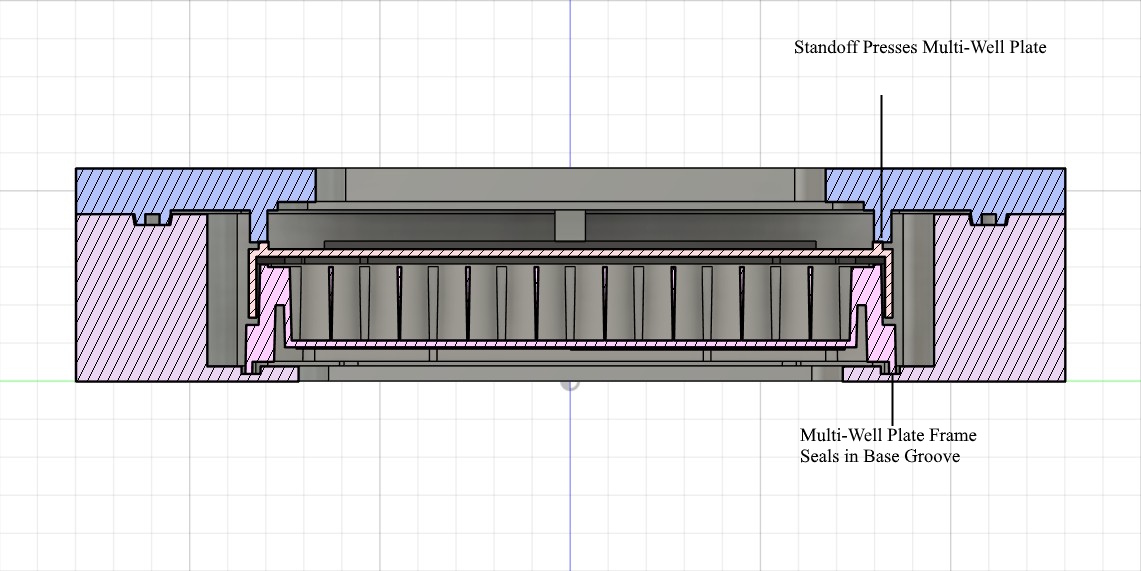
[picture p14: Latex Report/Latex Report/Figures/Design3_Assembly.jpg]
		
		\caption[]{Conceptual Design 3 Assembly}
		\label{fig:design3_Assembly}
	\end{subfigure}
	\caption[]{Conceptual Design 3 Base and Assembly Cross-Section}
	\label{fig:design3_Base_and_Assembly}
\end{figure}

The fundamental design for the third version is similar to that in version 2. This iteration of the design was focused on altering the features of the design to be most compatible with 3D printing and potential milling.

\subsubsection{Base}
As can be seen in \autoref{fig:design3base} The base interior was modified to feature rounded corners where possible. This meets the capabilities of manufacturing techniques such as CNC milling, where achieving a sharp 90\degree corner is not possible. 

The o-ring groove present on the bottom of the base was changed to be a shallow recess which fits the frame of the Greiner 96 well Microplates. This recess is intended to contain a gasket that will seal against the frame of the multi-well plate. 

The holes used to for mounting the lid to the base, were modified to fit an \href{https://www.netram.co.za/nuts-bolts/10092-threaded-inserts-m4-10-pack.html}{M4 threaded insert} that a screw will interface with. This eliminates the requirement for a nut that interfaces with a bolt.

The mating feature was modified slightly to use a thicker wall that would better suit the capabilities of a 3D printer which would be used to produce a prototype.

\subsubsection{Lid}
As can be seen in \autoref{fig:design3}, whilst the fundamental design was not altered, a few modifications were made for the purpose of producing the final prototype.

As shown in \autoref{fig:design3Lid_Top}, the mounting holes were modified with a recess that matches \href{https://www.netram.co.za/nuts-bolts/10102-491-7991-hexagon-socket-countersunk-screws.html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}{M4 countersunk screws} provided by netram electronics. This recess will allow the screws to sit flush with the lid. The screw is meant to interface with threaded inserts that will be set into the base. 

In order to achieve a proper seal within the chamber, the multi-well plate needs to be pressed into the gasket that will rest in the groove present in the base. The stand-offs shown in \autoref{fig:design3Lid_Bottom} were added in order to press the multi-well plate into this gasket. 

Additionally, as done with the base, the lid was modified to feature as many rounded corners as possible for compatibility with potential manufacturing techniques. 

\subsubsection{3D Printed Prototype}
The third design iteration was used as the final version for this project. This version was 3D printed to provide a physical prototype that will be demonstrated. The final 3D printed base and lid is shown in \autoref{fig:3dprintedprototypeparts}. The Greiner 96 Well Microplate fits into the prototype chamber as shown in \autoref{fig:3dprintedprototypeopen} and \autoref{fig:3dprintedprototypeassembled}.
\begin{figure}[H]
	\centering
	
	\caption{3D Printed Lid and Base of the Final Prototype}
	\label{fig:3dprintedprototypeparts}
\end{figure}

\begin{figure}[H]
	\centering
	
	\caption{3D Printed Prototype with 96 Well Microplate and Lid Removed.}
	\label{fig:3dprintedprototypeopen}
\end{figure}

\begin{figure}[H]
	\centering
	
	\caption{Assembled 3D printed prototype with 96 Well Microplate.}
	\label{fig:3dprintedprototypeassembled}
\end{figure}

% =====================================================

% ----------------------------------------------------
\ifstandalone
\bibliography{../Bibliography/References.bib}
\fi
\end{document}
% ----------------------------------------------------

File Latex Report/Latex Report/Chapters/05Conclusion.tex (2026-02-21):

% ----------------------------------------------------
% Conclusion
% ----------------------------------------------------
\documentclass[class=report,11pt,crop=false]{standalone}
\input{../Style/ChapterStyle.tex}
\begin{document}
% ----------------------------------------------------
\chapter{Conclusion} \label{ch:conclusion}
\vspace{-1cm}
% ----------------------------------------------------
% This CHAPTER only needs to be completed for the final report

% Summarise purpose of and motivation for the document (problem statement and scope) 

% Explain the final solution and link back to problem 

%Summarise the most important findings 

A useful experiment within cellular biology is long term cell imaging. Getting time-lapse footage of cell growth requires adequate incubation to ensure that the cell culture is able to grow uninhibited, and under the desired conditions. Stage-top incubators aim to solve this problem by providing an incubation chamber that is small enough to mount directly on top of existing microscopes that are present in most labs. The main issue with existing stage-top incubators is that they do not provide adequate containment capabilities for microbes that are classified as potentially lethal, such as those present in a bio-safety level three laboratory. 

This project aims to explore the possibility of developing a custom stage top incubator that is capable of functioning whilst providing suitable containment that allows these long term observations to occur within a bio-safety level three laboratory without the necessity for external containment.

This report documents the process of creating a conceptual design and prototype to demonstrate the bio-containment aspect of this project in order to determine the feasibility of taking on the full project for stage top incubation. For this purpose, a chamber is designed to house a Greiner 96 well microplate, and provide the capability to hermetically seal the multi-well plate inside, whilst still allowing for microscopy.

The design went through three major iterations, whereby feedback was used to alter and improve the design to a point whereby it could be 3D printed as a proof of concept.

Ultimately the conceptual design indicated that it would be possible to manufacture a bio-containment chamber that would be suitable for use within a BSL-3 lab. The design could be further improved upon to allow for environmental control. This shows that it would be feasible to undertake the project of designing a stage-top incubator with basic environmental control. 
% =====================================================
\section{Recommendations}
% Future recommendations for improvements in your project
The 3D printed model provided some insight into the performance of the bio-containment chamber. Whilst the prototype does successfully demonstrate the functionality of the chamber, it does indicate that there are areas where improvements could be made.

Whilst the stand-offs designed into the lid, that are used to press the multi-well plate into the gasket on the base, do provide enough force to prevent the plate from moving, the design does not take into consideration other multi-well plate manufactures, and so is isolated to working with the Greiner multi-well plate. Additionally it does not take into consideration the variance in plate heights between units. Further, with the primary mounting force originating in the four corners of the chamber, this allows for some elastic deformation at the stand-off positions which reduces the mounting force. 

% ----------------------------------------------------
\ifstandalone
\bibliography{../Bibliography/References.bib}
\fi
\end{document}
% ----------------------------------------------------

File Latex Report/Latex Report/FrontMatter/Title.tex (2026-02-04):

\thispagestyle{empty}
\begin{center}
    
\Huge

\vspace{5cm}

% Title
Conceptual Design for a BSL-3 Suitable Stage-Top Bio-containment chamber

\vspace{0.1cm}
%\large
%Micromouse X Subsystem

\vspace{2cm}
% UCT logo
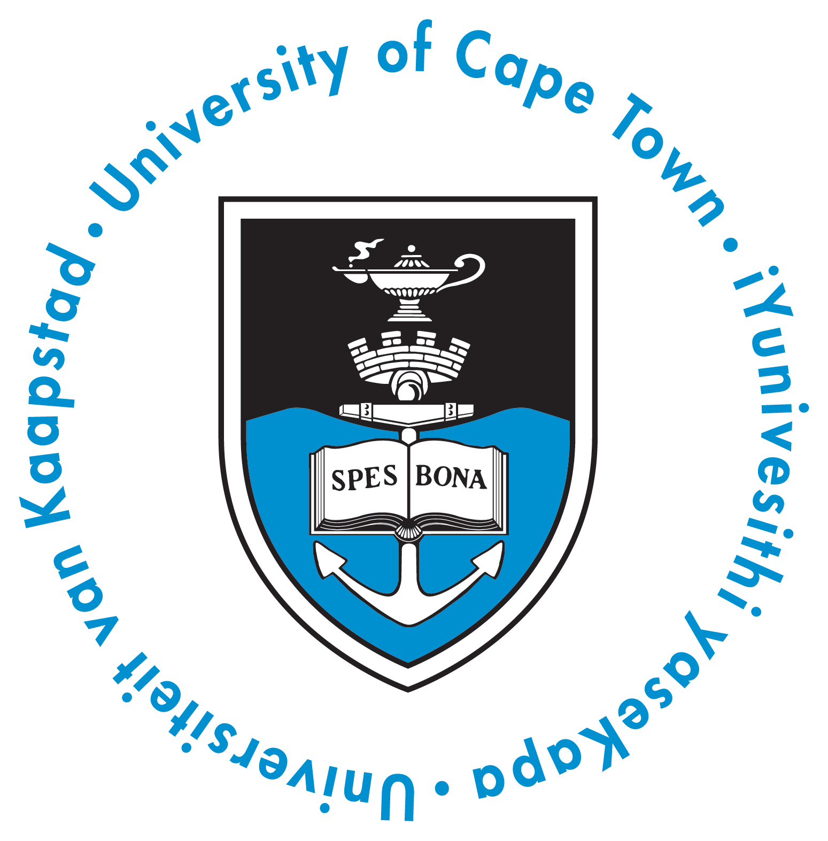
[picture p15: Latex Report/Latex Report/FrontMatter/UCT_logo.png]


\vfill

% My name
\large
\textbf{Prepared by:}\\
Joab Gray Kloppers

\vspace{1cm}

% My supervisor's name
\textbf{Prepared for:}\\
Mandy Mason\\
Robyn Verrinder\\
Justin Pead\\
University of Cape Town

\vspace{2cm}

% Today's date
\today

% To add keywords?
% \vspace{2cm}
% \textbf{Keywords:} Keywords here

\end{center}

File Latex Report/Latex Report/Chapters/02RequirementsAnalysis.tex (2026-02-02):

% ----------------------------------------------------
% Requirements Analysis
% ----------------------------------------------------
\documentclass[class=report,11pt,crop=false]{standalone}
\input{../Style/ChapterStyle.tex}
\begin{document}
% ----------------------------------------------------
\chapter{Requirements Analysis} \label{ch:reqAnalysis}
\vspace{-1cm}
% ----------------------------------------------------
% =====================================================
\section{Traceability Analysis}
Show how the requirements, specifications and testing procedures all link, \autoref{tab:matrix} is provided.

\begin{table}[h]
    \centering
    \caption{Requirements Traceability Matrix}
    \label{tab:matrix}
    \begin{tabular}{|c|c|c|c|}
        \hline
        \# & Requirements & Specifications  & Acceptance Test\\
        \hline
         1 & UR01 &  SP01 & AT01 \\
         \hline
         2 & FR01 & SP02,SP05 & AT03 \\
         \hline
         & &  & \\
         \hline
    \end{tabular}
\end{table}

\subsection{Traceability Analysis 1}
% Explain your thinking around how everything links.

\subsection{Traceability Analysis 2}
% Explain your thinking around how everything links.

% =====================================================
\section{Requirements}
The requirements for a micromouse power module are described in \autoref{tab:requirements}.
\begin{table}[h]
    \centering
    \caption{User and functional requirements of the power subsystem.}    \label{tab:requirements}
    \begin{tabular}{|c|l|}
        \hline
        \textbf{ Requirement ID} & \textbf{Description} \\
        \hline
         UR01 & \\
         \hline
         FR01 & \\
         \hline
         &  \\
         \hline
         &  \\
         \hline
    \end{tabular}
\end{table}

% =====================================================
\section{Specifications}
The specifications, refined from the requirements in \autoref{tab:requirements}, for the micromouse power module are described in \autoref{tab:specifications}.
\begin{table}[h]
    \centering
    \caption{Specifications of the sensing subsystem derived from the requirements in \autoref{tab:requirements}.}    \label{tab:specifications}
    \begin{tabular}{|c|l|}
        \hline
        \textbf{Specification ID} & \textbf{Description} \\
        \hline
         SP01 & User \\
         \hline
         &  \\
         \hline
         &  \\
         \hline
    \end{tabular}
\end{table}

% =====================================================
\section{Acceptance Testing Procedures}
% The table given below is an example of how you can present your ATPs. You are welcome to change or adapt it to your need. The example given is not a valid ATP description.

\begin{table}[h]
  \begin{center}
    \caption{Subsystem acceptance tests}
    \label{tab:tests}
    \begin{tabular}{| >{\centering\arraybackslash}m{1cm} | m{4cm}| m{5cm}| m{5cm}|}
      \hline
      \textbf{ID} & \textbf{Description} & \textbf{Testing Procedure}& \textbf{Pass/Fail Criteria} \\   
      \hline
      AT01 & Powers on & \tabitem \newline\indent\tabitem & \\
      \hline
       &  &\tabitem \newline\indent\tabitem  & \\
      \hline 
    \end{tabular}
  \end{center}
\end{table}

% ----------------------------------------------------
\ifstandalone
\bibliography{../Bibliography/References.bib}
\fi
\end{document}
% ----------------------------------------------------

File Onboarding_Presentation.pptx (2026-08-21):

## Stage Top bio-containment with consideration for a BSL-3 Lab

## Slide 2

The Goal:
- Live-Cell Imaging of Microbes in BSL-3 Labs
- Low Cost Equipment
- Stage-Top Incubator Format
The Problem:
- Commercial Incubators not BSL-3 Containment viable
- Commercial Incubators not Suitable for Autoclave Sterilisation
- Commercial Incubators are Costly

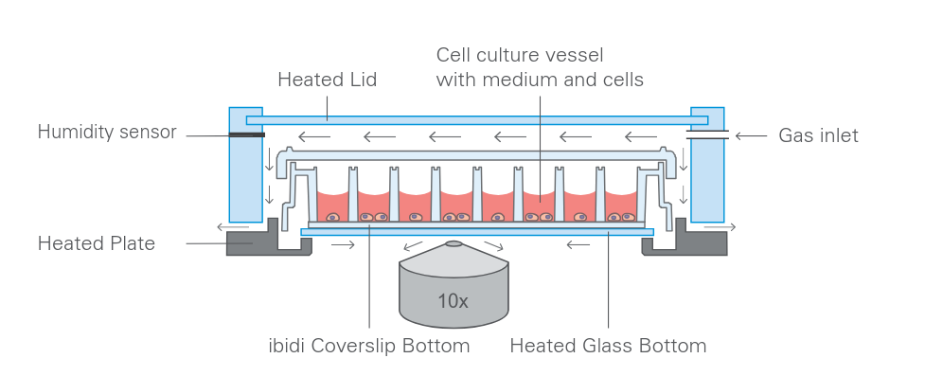
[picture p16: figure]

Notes: It would be beneficial to perform long-term live cell imaging of microbes such as Mtb to observe the long term behaviour.
A simple and low cost solution would be to live monitor these cultures using a low cost microscope such as the Iolight microscope, however typically this would require having a small sealed plate which can be placed on the microscope, and then the entire microscope is placed inside a conventional incubator to allow the cells to grow.

This is not ideal for several reasons:
Complicates the sterility/containment procedure
Takes up significant space in the incubator, thus limiting the functionality of both the incubator and number of observations that can be done at one time
Introduces significant variance in the culture environment and optical results since the incubator introduces lots of vibrations, and temperature stability is dependant on the usage of the incubator.
Limits the ability to log incubator data continuously during the observation

Current stage top incubator systems such as the Zeis/Pecon stage top incubator, Ibidi stage top incubation system and the Tokai Hit system provide very good control of their stage top incubators that are designed to fit with industry standard microscope stages, such as the k-type. However they lack the critical feature of being fully sealed to prevent contamination.

These three solutions all encorperate a design where the Gas flow (CO2/O2/humidity controlling gas flow) is meant to flow through the chamber and then pasivly get exhausted around the bottom of the container through gaps and holes in the incubator. This is not ideal in a BSL-3 environment as it leads to workspace contamination.

Therefore this project is aiming to try and determine if it is viable to produce a product that could function as a fully contained incubator whilst still fitting ontop of a microscope stage, which allows for research of long term cell performance, whilst being placed on worktop outside of a standard incubator and being fully contained to meet BSL-3 standards.

## The project goal

Immediate Goals
- Determine feasibility of designing a stage-top bio-containment system suitable for BSL-3
- Identify basic specifications required for the design of a BSL-3 Incubator

Future Goals
- Design and prototype a temperature controlled incubator that can operate in a BSL-3 lab.
- Determine feasibility of including CO2/O2 concentration control

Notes: The current scope of this project is limited to just determining the feasibility of designing an incubator with basic temperature control that can be used in a BSL-3 lab.

For feasibility:
Commercial solutions are assessed to determine the functionality that is offered by them, aspects that prevent them form working in a BSL-3 Lab. ETC
Determine the containment requirements that allow a containment system to function within a BSL-3
Determining the environmental control specifications required to obtain sufficient incubation.
Determine the sterilization techniques that are required for a BSL-3 lab

A part of determining the feasibility of this system, is to determine if it is possible to hermetically seal a culture vessel within a container whilst still allowing for optical viewing.
This includes:
Prototyping an enclosure which holds a 96 well plate.
Prototyping an enclosure which offers complete hermetic seal comparable to an IP68 enclosure
Prototyping an enclosure which provides suitable optical clarity for low magnification microscopy

If it is feasible to begin prototyping and performing a conceptual design, the eventual goal is the following:
Prototype a stage top incubator that is completely hermetically sealed.
Prototype a stage top incubator that can maintain a stable temperature required for cell growth.
Prototype a stage top incubator that is capable of being sterilized using existing BSL-3 protocols.
Prototype a stage top incubator that can fit ontop of a low magnification microscope for long term live cell imaging
Allow for the possibility of CO2/O2/Humidity regulation
Allow for the possibility of compatibility with several different culture dishes.

## Prototyping V1

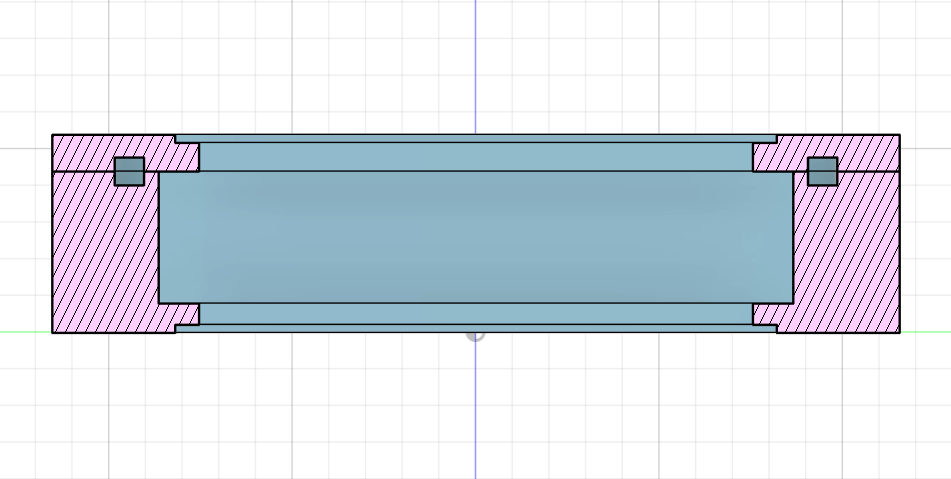
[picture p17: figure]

O-Ring Groove

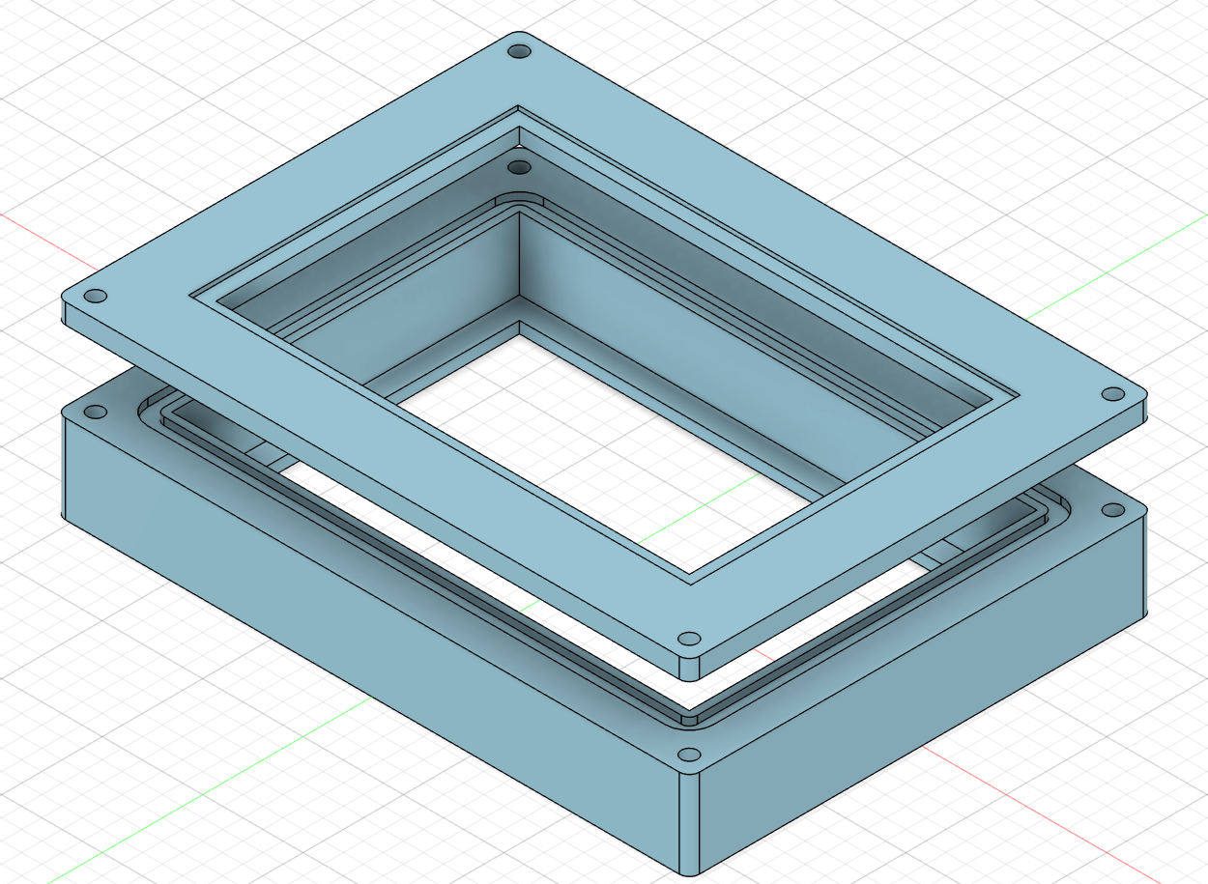
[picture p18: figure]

Top and Bottom Plate Insert

Plate Cavity

Secured Using Bolts

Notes: First Round used a simple box design with a cavity that seats the multi-well plate.
The box will use plates on the top and bottom that are set in place using epoxy or glue sealant. These will be either both glass, or glass and aluminum plate.

This design uses a rudimentary grove based into both the lid and base with sharp corners for an o-ring.

The entire plate will be completely sealed within the chamber using the two plates on the outer surfaces, as well as the o-ring that sits in the groove.

## Prototyping V3.3

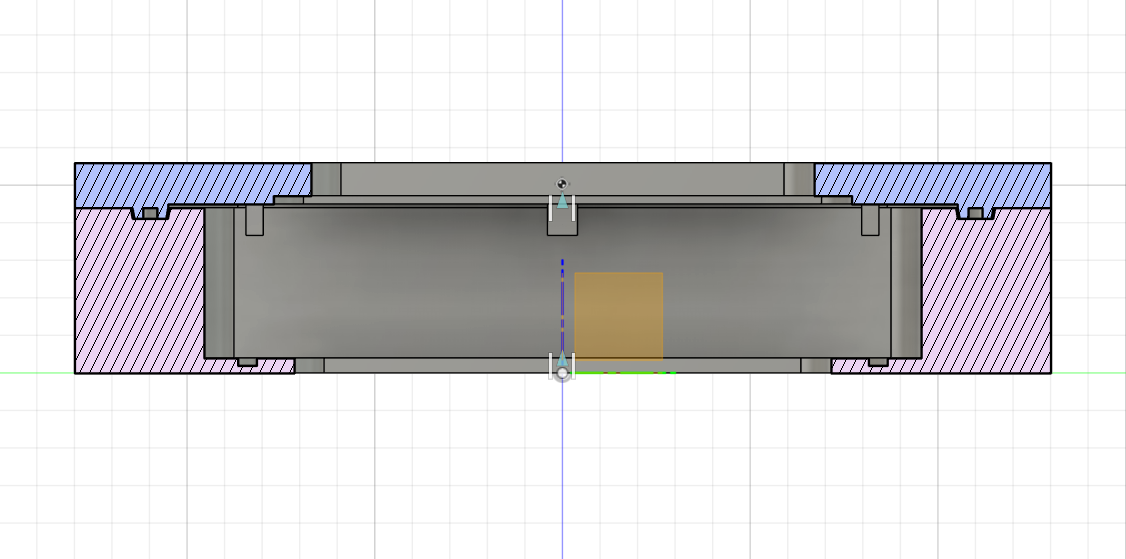
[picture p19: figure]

Recessed O-Ring Groove

Plate Lid Standoffs

Plate Cavity

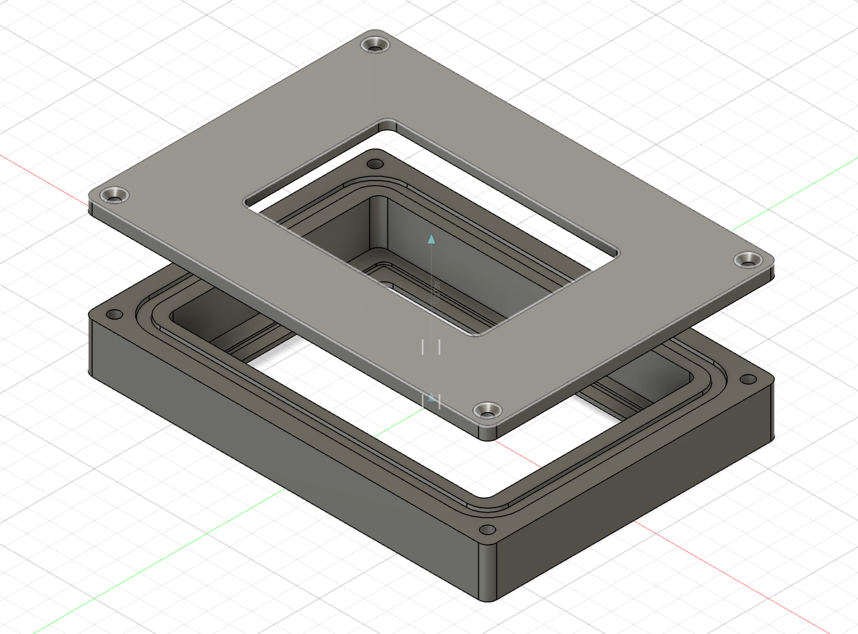
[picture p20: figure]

Sealing Plate Recess

Top Plate Insert

Un-Obscured
Viewing port

Secured Using
Counter Sunk Screws

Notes: After 2 rounds of revision the latest edition updates and improves several parts
O-Ring groove has been revised to use a recessed design that allows for aligned mating of lid and base
Bottom viewing plate removed and top viewing plate insert moved to inside of lid for better pressure seals.
Base uses a groove that seals against the base of the multi-well plate to allow for more direct optical viewing
Lid includes standoffs to press the plate into the base for sealing.
The lid is mounted to the base using a counter sunk screw and a threaded insert in the base.

## Summary & Future Improvements

- Silicone O-Ring Used to Seal Lid
- Silicone Gasket Used to Seal Base
- Compatible with Greiner Multi-well plates
- Secured using countersunk screws
- Unobstructed viewing from Top and Bottom

Screw Mounting Tedious, and Supply Insufficient Mounting Pressure
New Mechanism to Apply pressure to Multi-Well Plate
Two Sealant Mechanisms Sub-Optimal
Provisions for Gas and Temperature Control

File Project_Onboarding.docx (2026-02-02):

# Stage Top Incubator with Consideration for a BSL3 Laboratory

This project is focused about the development of a stage top incubator that can be used within a BSL3 laboratory. The desired output is to identify key constraints, requirements and conceptual designs for an incubator that can be mounted onto a microscope stage whilst containing the sample suitably enough for the use within a biosafety level three (BSL-3) laboratory. The intended use case for this project would be for researchers intending to perform long term live-cell imaging for microbes that require BSL3 labs for research.

# Key Concepts and Terminology

BSL-3 (Biosafety Level 3): A laboratory bio-containment standard used for working with biological agents that can cause serious and potentially lethal disease via the inhalation route.

Stage top incubator: Laboratory equipment used to maintain controlled environmental conditions (temperature, humidity, CO2 concentration, etc) that is capable of being utilised on top of a microscope stage

# Background and Context

In order to perform live-cell imaging, the cells need to be kept in an environment that is suitable for the cells to stay alive. This is done by utilizing an incubator that maintains the correct temperature, humidity, pH and Oxygen levels that are required by the cells. One method of incubating a sample whilst performing imaging is the use of a stage top incubator, This is an incubator which is designed to fit onto the microscope stage and be a self-contained system that does not require incubation of the entire microscope. This is particularly useful as it minimises the space requirement to perform imaging as well as reducing the complexity of set-up as

Live cell imaging requires that the cell culture is kept in an environment that is suitable for growth of the cell culture. This can be done with the use of a stage top incubator which provides a small enclosed environment that is kept stable and controlled. A stage top incubator is designed to mount onto an inverted microscope stage. However, most commercial solutions are not BSL-3 laboratory compliant, Additionally these commercial solutions are often costly and this limits the useability within the lab. For this reason, this project was started to assess the feasibility of designing a stage top incubator that can work within a BSL-3 lab.

The assessment of commercial solutions provided a basic understanding of the environmental control specifications that are widely used, as well as a basic understanding of the functionality of the solutions.

It was determined that to provide a minimum viable product, the incubator should at minimum provide temperature control whilst remaining fully sealed to the external environment. Based on this, a conceptual design process was started.

# Audience

This document is intended for the following:

- Researchers and engineers designing lab equipment for high containment fields.
- Researchers exploring design process for stage top incubators that can be utilized in BSL-3 labs.
- Researchers exploring low cost stage top incubators that can be utilized instead of costly commercial solutions in low containment fields

# Goals and Scope

The goals associated with this project are as follows:

- Explore commercial solution and assess functionality.
- Provide a scope for the possible design of a low cost stage top incubator that can be used in a BSL-3 laboratory.
- Identify the key specifications required to produce a design that complies with BSL-3 as well as cell culture requirements.
- Determine if the possible design for a low cost incubator is feasible.
- Produce suitable documentation for future prototyping/ design projects.

The scope of this project is limited to the following:

- Currently preliminary research and conceptual design
- Currently focus on basic environmental temperature control suitable for Mtb. (subject to change)
- Currently focus on compatibility with low-magnification, bench-top microscopes.
- Focus on compatibility with microtiter plates. (subject to change)
- Focus on BSL-3 containment standards.

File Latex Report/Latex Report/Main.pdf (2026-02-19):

# Conceptual Design for a BSL-3 Suitable

# Stage-Top Bio-containment chamber

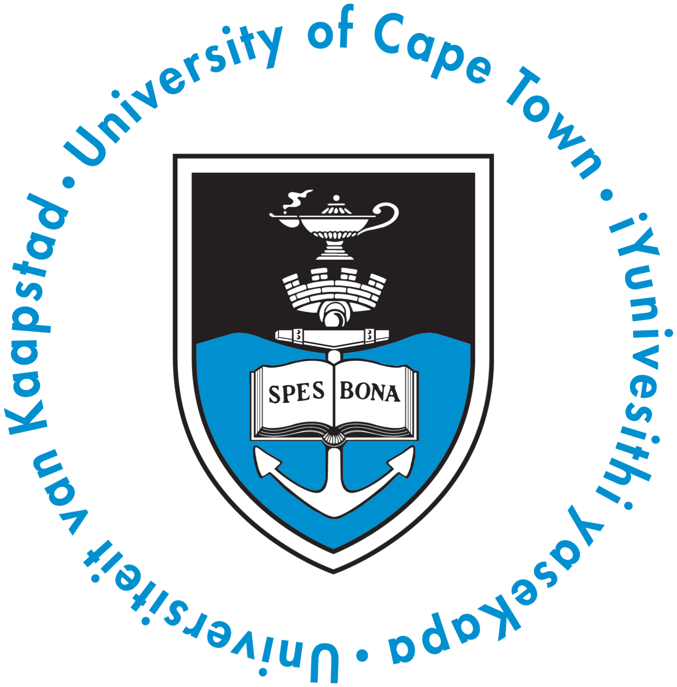
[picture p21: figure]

Prepared by:
Joab Gray Kloppers

Prepared for:
Mandy Mason
Robyn Verrinder
Justin Pead
University of Cape Town

February 19, 2026

# Contents

1 Introduction | 1
2 Research | 2
3 Specification Analysis | 7
4 Conceptual Design | 13
5 Discussion and Results | 19
6 Conclusion | 20
Bibliography | 21

ii

# Chapter 1

# Introduction

## 1.1 Background and Summary

Long term Live-Cell imaging is a very useful research tool when determining long term behavior of cell cultures in various situations. Commercial solutions are unable to provide adequate containment for the use within a Bio-Safety Level 3 (BSL-3) and often require the use of a separate containment

enclosure, which introduces additional costs and complexity.

This project focuses on the conceptual design of a low-cost Stage-Top Incubator that is capable of being utilized within a BSL-3 laboratory, without the requirement for additional containment. The primary focus with this project is specific suitability with Mycobacterium tuberculosis, however does consider other microbe requirements

## 1.2 Scope and Limitations

This project is limited to the following:

- Preliminary Research
- Temperature Control
- Compatibility with Multi-Well microtiter plates
- Primary compatibility with Mycobacterium tuberculosis (M. tb).

This project is limited to compatibility with a BSL-3 Lab and does not consider higher containment requirements. The environmental control aspects of the incubator are limited to just temperature control for the preliminary conceptual design. The initial design is limited to compatibility with a multi-well microtiter plate. The use case of this project is limited to that of Mycobacterium tuberculosis.

# Chapter 2

# Research

The conceptual design began with assessing existing commercial products to identify the key environmental control specifications required for the incubator to function correctly. Additionally, this was useful in identifying why the commercial products are incompatible with a BSL-3 lab when used without a separate external biological containment mechanism.

## 2.1 Zeis/Pecon

The Zeis/Pecon stage top incubator utilities four modules to control the environmental conditions

within the incubator stage.

The Pecon Temperature Module S[1] regulates the temperature of the incubator. It has four 8-pin

connectors that are used for temperature control of heated components such as the Incubator lid, incubator base, microscope objective and humidifier device. The temperature module is the base module for the entire incubation system, providing electrical power and communications to all connected devices. It directly connects to the CO2 module to provide power, communication and makes a connection to the gas circulation system to heat the gas flow provided to the incubation chamber. The temperature module requires an external device such as a PC or compatible microscope for operation as it does not have any control panel. The module maintains culture temperature by monitoring and controlling the temperature of the incubator base, lid and optionally the microscope objective. The module infers the culture temperature using pre-set temperatures, or by performing a pre-experiment calibration whereby an identical set-up is placed in the chamber with the included culture temperature sensor to tune the required chamber temperatures.

The Pecon CO2 Module S[2] attaches to the temperature module for electrical power and communication,

and provides CO2 concentration control to the airflow passed into the incubation chamber. The CO2 module circulates gas throughout all the connected units and mixes the gas before pumping the resultant mixture into the incubation chamber. The module contains a CO2 sensor which monitors the concentration of CO2 in the gas mixture, and controls the release of pure CO2 into the mixing chamber in order to maintain the desired CO2 concentration. Due to the method of operation, it requires a >95% purity CO2 supply.

The Pecon O2 Module S[3] attaches to the CO2 module for electrical power and communication. This

module functions similarly to the CO2 module, however it regulates the concentration of O2 present in the gas mixture by controlling the release of a pure N2 supply into the air mixture to displace the O2 present. This method of O2 displacements means that the O2 module is only capable of providing hypoxia conditions by lowering O2 concentration. Due to the method of operation, it requires a >99%

purity N2 supply.

2.2. Ibidi

Both the CO2 module and O2 module are supplied with a humidifying bottle which functions by bubbling the the gas airflow thorugh distilled water to raise the relative humidity (RH). The Pecon Heating Device Humidity S1[4] is an optional module which connects to the Temperature module to

heat the humidifying bottle to increase the RH and maintain adequete gas temperature provided to the incubation chamber

The incubator stage includes a heated glass topped lid[5] and a heated insert which accepts mounts for

the different culture vessels used in microscopy. The heated insert directly heats the culture medium through physical contact, and the heated lid provides radiative heating and condensation prevention by heating the glass panel directly. The insert supports perfusion experiments utilising two ports which allow tubes to be run to the culture.

## 2.2 Ibidi

The Ibidi stage top incubator functions similarly to the Zeis/Pecon module, however it makes use of

three modules to maintain environmental conditions.

The Heating System Silver Line[6] module regulates the temperature of the incubator. It makes use

of 6 independent channels connected via 4 ports, two of which connect to two channels each. These channels are used to monitor and control the temperature of the components used in the system, such as the heated lid and heated plate. The module maintains culture temperature by monitoring and controlling the temperature of the heated lid, heated base and optionally the microscope objective. The module infers the culture temperature using pre-set temperatures, or by performing a calibration whereby an identical set-up is placed in the chamber with the included thermocouple to tune the required chamber settings to meet the desired culture temperature. The temperature module can be operated using the on device buttons and screen, or it can be connected to a PC for control using the free software. The temperature module does not heat the gas mixture.

The Gas Incubation System[7] comes in two different models, the CO2 - Silver Line and the CO2/O2

- Silver Line. The difference between these two systems is the former is only capable of regulating CO2 concentration, where as the latter has the ability to regulate O2 concentration as well as CO2 concentration. The module has three gas inputs for pressurised air, CO2 and N2. The CO2 and N2 are fed into and mixed with the pressurised air to obtain a mixture with the desired CO2 and O2 concentrations. The module then heats the gas mixture before pumping it to the incubation chamber. If the CO2 only module is used, the N2 air input is still present on the device, however it is sealed internally and so the module is unable to regulate O2 concentration. Due to the method of using N2 to displace O2 in the mixture, this system is only capable of producing hypoxia environments. The gas incubator module has two output ports which are used in conjunction with the Humidifying column to mix the dry gas with humidified gas to obtain the desired relative humidity as shown in Figure 2.1. The gas incubation module has two electrical connections, one to control the heating of the humidifying column and gas line, and the second to connect to the humidity sensor present in the incubation chamber. The module can be operated using the on device buttons and screen, or it can be connected to a PC for control using the free software.

The Humidifying column[7] works by bubbling the airflow through heated, distilled water to increase

2.3. Tokai-Hit

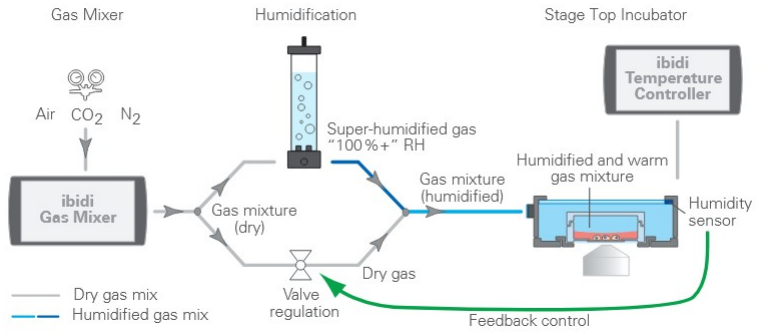
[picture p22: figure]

Figure 2.1: Diagram Showing the Humidity Control Mechanism Used by the Ibidi Gas Incubation System [7]

the relative humidity to approximately 100% RH. This is then mixed with dry gas to obtain the desired % RH.

The Ibidi incubation chamber comes in two versions, one version supports culture mediums with Petri dishes and slides, the second version supports multi-well plates. The Petri dish/Slide version of the

chamber supports perfusion experiments using two ports which allow tubes to be run to the culture. Both chambers directly heat the culture medium through physical contact and provide radiative heating and condensation prevention by heating the glass lid.

## 2.3 Tokai-Hit

The Tokai-Hit system functions similarly to the Pecon and Ibidi systems however it utilises a single module to regulate the environmental conditions for temperature and CO2. Humidity is controlled by a heated water bath inside the chamber, and O2 control is achieved by utilising an optional module which then overrides all gas control.

The Tokai-Hit STXG/STXF[8] temperature and CO2 controller regulates both temperature and CO2

concentration in the incubation chamber. The controller utilises a single connector to control all component temperatures such as the Lid heater, bath heater, stage heater and optional microscope objective heater. The module infers the culture temperature using pre-set temperatures, however it can operate in feedback mode whereby a sensor directly monitors the temperature of the culture medium and automatically adjusts the component temperatures to meet the desired set point. The module can be operated using the built in touch screen or it can be connected to a PC for control using software.

The STXG and STXF models both provide airflow to the incubation chamber, however the STXG model is capable of controlling the CO2 concentration by feeding supplied CO2 into the gas mixture until the desired concentration is reached, then pumps the mixture to the incubation chamber. The STXF model is unable to regulate CO2 concentration, and so requires a pre-mixed pressurised CO2/air.

The incubator chamber uses a single design that is compatible with most major culture vessels including Petri dishes, slides and multi-well plates. This chamber supports perfusion experiments, drug administration and direct culture temperature measurement via access ports designed into the lid. The humidity inside the incubation chamber is maintained via a water bath that is present inside the chamber, and which is heated by the STXG/STXF module.

The STXG/STXF modules can optionally be connected to a separate CO2/O2 unit which overrides

2.4. OkoLab

the gas control mixture and allows for the optional control of O2 concentration.

## 2.4 OkoLab

The OkoLab utilises three modules to regulate environmental conditions within the incubation chamber

The OkoLab H301-T-UNIT-BL-PLUS[9] unit is responsible for maintaining the thermal conditions

within the chamber enclosure. It operates by monitoring and controlling the temperature of the chamber base, lid and optionally the microscope objective. This in turn heats the sample to the desired temperature. This heating unit is capable of sample temperature feedback utilising a thin thermocouple that can be placed in distilled water near the sample to obtain more accurate sample temperature control. Otherwise the unit is capable of using pre-sets/calibrations to infer sample temperature based

on enclosure temperatures. The heating unit can be operated via a computer using available software or using optional touch screen accessory. The heating unit is capable of interfacing with the Oko-Lab Bold Line Gas Controllers. The temperature module supports a programmed temperature cycle mode where it cycles between set temperatures.

The CO2-O2-UNIT-BL[10] modules come in a variety of formats, differing in the O2 control ranges they support. The CO2-O2-UNIT-BL [0-20; 1-95] variant supports O2 concentration range from 1% to 95%. This model requires a pressurised supply of CO2, N2 and O2 to obtain the desired gas mixture,

alternatively compressed air or an air pump can be connected to the N2 supply which limits the functionality to just CO2 concentration control. The CO2-O2 BL line all have the capability to directly interface with the Temperature unit to allow communication between the two units.

The HM-ACTIVE[11] operates by passing the gas mixture over heated water to increase the RH. The

water temperature can be altered to control the RH of the out flowing gas. The humidity control unit is controlled by the gas mixture unit.

The H301-K-FRAME[12] uses a design that is compatible with most major culture vessels, each using

a different sample holder. The chamber is also designed to work with various lids depending on the required application. The chamber supports perfusion experiments and microfluidic experiments. The chamber directly heats the culture medium through physical contact and provides radiative heating and condensation prevention by heating the glass lid

## 2.5 Shortfalls

### 2.5.1 Containment

The commercial solutions provided by Zeis/Pecon, ibidi, Tokai Hit and OkoLab are all unable to

operate independently, without an external containment chamber, within a BSL-3 laboratory due to a fundamental design choice present in all solutions. The Incubation chambers are designed to have an imperfect containment seal to allow the incoming gas flows to passively exhaust out the base and any gaps in the enclosure. This can be seen in the diagram shown in Figure 2.2 which is provided by ibidi.

This means that the exhausting air is unfiltered and may be contaminated with the cells present during the experiment, which can lead to contamination of the surrounding workspace. For this reason, when

2.5. Shortfalls


Figure 2.2: Diagram Showing the Gas Flow within the ibidi Multi-Well Incubation Chamber

working with potentially lethal pathogens, it is required that the incubator be placed within a larger containment vessel to ensure that contamination does not occur.

### 2.5.2 Disinfection and sterilisation

All equipment inside of a BSL-3 lab requires either sterilisation or disinfection depending on the equipment use or properties. Sterilisation is used to kill almost all micro cellular activity on an item and is rated on the Sterility Assurance Level (SAL) which indicates the probability of a single microbe

surviving. Disinfection is used to kill enough micro cellular life to achieve a safe enough level required by the laboratory. Examples of sterilisation and disinfection techniques are as follows:

- Sodium hypochlorite(bleach), is useful as a broad spectrum disinfectant and is effective against bacterial spores[13], [14], [15].
- hydrogen peroxide, which is a very effective sterilising chemical[13] and is often used for sterilisation of tool, biological safety cabinets and laboratories[16].
- Quaternary Ammonium Compounds, which provides cost effective but low level disinfection[13], [14], [15].
- Alcohols, which offer an intermediary disinfection [13], however are ineffective against spores[14]
- Autoclave, which provides extremely effective sterilization using a pressurized containment vessel filled with steam heated to approximately 120◦C

The aforementioned commercial solutions specify the use of concentrated alcohol solutions such as ethanol or isopropanol, which are not suitable for adequate sterilisation of microbes which produce spores, such as Mycobacterium tuberculosis, which is the primary cell considered in this feasibility study. Furthermore, Most of these solutions do not specify whether they are Autoclave compatible, leaving compatibility with autoclave sterilisation uncertain. However, the Tokai hit and Zeis/Pecon

incubator specifically mention that they are not compatible with autoclaves.

### 2.5.3 Key Takeaways

The discussed commercial solutions are incompatible with experiments that require stage top incubation for stand alone, long term, live cell imaging within a BSL-3 lab. This is because of the lack of adequate containment capabilities as well as the incompatibility with disinfection and sterilisation methods required by the microbes of interest.

# Chapter 3

# Specification Analysis

## 3.1 Commercial Assessment

The commercial solutions from Zeis/Pecon, Ibidi, Tokai-Hit and Okolab are assessed for their primary

method of operation as well as the environmental control specifications provided by each product.

### 3.1.1 Zeis/Pecon

The incubation system provided by Zeis/Pecon utilises four modules for the control of the four major

environmental conditions. A temperature unit for thermal control, a CO2 unit for CO2 concentration control, an O2 unit for O2 concentration control and a humidifying bottle for humidity control.

The heating unit monitors and controls the temperature of the culture sample through heating of the incubation chamber, gas airflow and humidifying bottle.

The CO2 unit monitors and controls the concentration of CO2 being pumped into the incubation chamber by controlling the release of pure CO2 gas into the internal mixing chamber.

The O2 unit monitors and controls the concentration of O2 being pumped into the incubation chamber by controlling the release of Pure N2 gas into the circulating gas in order to displace the O2 present. Thus can only achieve hypoxia conditions.

The humidifying unit operates by bubbling the gas mixture through heated water to achieve a close to 100% RH ro prevent the drying of the culture media.

The Zeis/Pecon incubation system as a whole has the specifications shown in Table 3.1.

3.1. Commercial Assessment
Temperature Control Range | Ambient - 60°C (Recommended max 45°C)
Control Accuracy | ±0.15%
Control Resolution | Internal Loop: 0.01°C User Parameter: 0.1°C
CO2 Control Range | 0.0 - 8.0 vol% (8.1-10 vol% with Uncepecified Reduced Accuracy)
Control Accuracy | ±2 vol%
Control Resolution | Internal Loop: 0.01 vol% User Parameter: 0.1 vol%
O2 Control Range | 0.0 - 21.0 vol%
Control Accuracy | ±0.05 vol%
Control Resolution | Internal Loop: 0.01 vol% User Parameter: 0.1 vol%
Operation | PC or Suitable Microscope required
Compatibility | Petri-Dishes, Chambers, Chamber Plates, Cham-ber Slides, Multi-Well Plates

Table 3.1: Specifications for Zeis/Pecon Incubation System [1], [2], [3], [4]

### 3.1.2 ibidi

The incubation system provided by Ibidi utilises three modules to maintain the environmental conditions within in incubation chamber. A temperature unit for thermal control, a CO2/O2 unit for CO2 and

O2 concentration control, and a humidifying column for humidity control.

The heating unit monitors and controls the temperature of the culture sample through heating of the incubation chamber.

The CO2/O2 unit monitors and controls the concentration of both CO2 and O2 being pumped into

the incubation chamber by controlling the release of pure CO2 and N2 into the gas mixture. The release of N2 displaces oxygen present in the air and so the system is only capable of producing hypoxia conditions. The CO2/O2 unit is also responsible for the heating of the gas mixture as well as the

heating of the humidifying column and gas tube.

The humidification control system works by controlling the mix of dry gas with humidified gas which is obtained through bubbling the dry gas flow through heated distilled water.

The Ibidi incubation system as a whole has the specifications shown in Table 3.2.

3.1. Commercial Assessment
Temperature Control Range | Ambient + 5°C - 50°C
Control Accuracy | ±0.2°C with ±0.5°C uniformity
Control Resolution | User Parameter: 0.1°C
CO2 Control Range | 0.0 - 15.0 vol%
Control Accuracy | ±0.2 vol% + 3% of Reading
Control Resolution | User Parameter: 0.1 vol%
O2 Control Range | 0.5 - 21.0 vol%
Control Accuracy | ±0.2 vol% (typical), ±0.7 vol% (max)
Control Resolution | User Parameter: 0.1 vol%
Humidity Control Range | Supply RH - 99% RH
Sensor Accuracy | ±2.5%
Control Resolution | 0.1%
Operation | On Device Controls or Connected PC
Compatibility | Petri-Dishes, Chamber Slides, Multi-Well Plates

Table 3.2: Specifications for Ibidi Incubation System [6], [7]

### 3.1.3 Tokai Hit

The incubation system provided by Tokai hit utilises one or two modules to maintain the environmental conditions within the incubation chamber, depending on the parameters that are desired to be controlled. The STXG/STXF module is capable of regulating both temperature conditions and CO2

gas concentration. An additional unit, STX-CO2O2, can be connected to the system to override the gas mixture control, and provide control for CO2 and O2 concentration.

The STXG/STXF unit monitors and controls the temperature of the culture sample through heating

of the incubation chamber. Additionally this unit is capable of regulating the concentration of CO2 being pumped into the incubation chamber. The STXG model can regulate the CO2 concentration by controlling the release of pure CO2 into the gas mixture, whereas the STXF module requires a pre-mixed pressurised air supply with 5% CO2.

O2 concentration can be achieved using a separate optional module which provides full gas concentration control.

Humidity in the incubation chamber is controlled through a heated water bath that is situated inside the chamber, and so forces a constant high relative humidity.

The specifications for the STXG and STX-CO2O2 incubation system is shown in Table 3.3.

3.1. Commercial Assessment
Temperature Control Range | Ambient +5°C - 65°C
Control Accuracy | ±0.3°C at heater surface
Control Resolution | User Parameter 0.1°C
CO2 Control Range | 5% vol - 20% vol
Control Accuracy | ±0.1% vol
Control Resolution | User Parameter 0.1% vol
O2 Control Range | 0.1% vol - 18% vol
Control Accuracy | —
Control Resolution | —
Operation | On Device or Connected PC
Compatibility | Petri-Dishes, Chamber Slides, Multi-Well Plates

Table 3.3: Specifications for the Tokai Hit Incubation System [8]

### 3.1.4 OkoLab

The incubation system provided by OkoLab utilises three modules to maintain the environmental conditions. A temperature unit for thermal control, a gas unit for CO2 and O2 concentration control and a humidifying bottle.

The heating unit monitors and controls the temperature of the temperature of the culture sample through heating of the incubation chamber.

The CO2/O2 unit monitors and controls the concentration of both CO2 and O2 being pumped into the

incubation chamber. The gas module is capable of working with a mix of concentrated O2, concentrated CO2, and concentrated N2 to obtain a complete control of the gas mixture being passed into the incubation chamber. Alternatively, the unit can operate with a supply of pressurised air, concentrated N2 and concentrated CO2 to get less complete atmospheric control.

Humidity control is obtained by bubbling the gas mixture through heated water to increase the relative humidity.

The specifications for the OkoLab incubation system is shown in Table 3.4

3.2. Requirements
Temperature Control Range | Ambient +3°C - 60°C
Control Accuracy | ±0.1 for sample feedback, ±0.3 for chamber feed-back
Control Resolution | User Parameter 0.1
CO2 Control Range | 0% vol - 20% vol
Control Accuracy | ±0.2% vol at 5% vol
Control Resolution | User Parameter 0.1% vol
O2 Control Range | 0% vol - 95% vol (using Pure O2 source, otherwise 20% max)
Control Accuracy | ±0.2% at 5% vol
Control Resolution | User Parameter 0.1% vol
Humidity Control Range | 26% RH - 95% RH at 50
Control Accuracy | ±1%
Control Resolution | User Parameter 1%

Table 3.4: Specifications for the OkoLab Incubation System

## 3.2 Requirements

The final goal of this project is the development of a stage top incubator that can be used to do long term observations of M. tb without the requirement of a large external incubation chamber.

However this report focuses on determining the feasibility of undertaking this project, and so has a reduced set of requirements aimed at scoping the fundamental aspects that would be required to understand the project goal. Therefore the requirements for this project include the following:

- Containment of Mycobacterium tuberculosis (M. tb)
- Compatibility with low magnification microscope stage
- Compatibility with a BSL-3 laboratory
- Compatibility with a 96-well culture vessel

This project focuses on the main aspect of bio-containment within a BSL-3 lab and how that can be achieved with a format that is compatible with the growth vessels and microscopy standards that are utilised for this kind of experiment.

## 3.3 Specifications

The specifications for the commercial solutions were assessed to obtain an understanding of specifications this project would need to meet in order to achieve a incubation system that would provide suitable conditions required for this type of long term imaging with cell cultures.

Table 3.5 shows the list of specifications that were decided on based off the specifications for the commercial solutions shown above. These specifications fall within those provided by commercial

3.4. Feasibility
Temperature Control Range | Ambient - 55
Temperature Accuracy | 0.2
Temperature Resolution | 0.1
CO2 Control Range | 0% vol - 15% vol
CO2 Control Accuracy | 0.1% vol
CO2 Control Resolution | 0.1% vol
O2 Control Range | 0.5% vol - 20% vol
O2 Control Accuracy | 0.1% vol
O2 Control Resolution | 0.1% vol
Humidity Control Range | 90% RH - 99%RH
Humidity Control Accuracy | —
Humidity Control Range | —

Table 3.5: Derived Specifications for the Continuation of this Project.

solutions and should facilitate the incubation of most cell cultures.

## 3.4 Feasibility

discus whether undertaking this project is feasible.

# Chapter 4

# Conceptual Design

The main focus on this report is centred about achieving a bio-containment system that allows for observing cultures grown in a 96-well plate. The system must ensure that no contamination can occur from the cells grown inside the container.

This section aims to describes the steps and decisions taken in the process of making a conceptual design for a containment vessel that meets the requirements mentioned in chapter 3. This conceptual design will help to determine the feasibility of taking this project further and incorporating incubation techniques which will enable the bio-containment vessel to be utilised as an incubation chamber that can be used for long term experimentation independently from traditional laboratory incubation cabinets

## 4.1 Design Iterations
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

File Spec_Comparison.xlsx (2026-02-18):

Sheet: Specification Comparison
 |  | Temperature Control | Gas Control
 | Pecon Incubator (Zeis)
 |  | Temp Module S | Heating Insert P Lab-Tek TM S1 | Incubator PM S1 |  | CO2 Module S | O2 Module S | Heating Device Humidity S
Range |  | Ambient to 60°C (Recommended 45°C) |  |  |  | 0.0 to 8.0 Vol-% | 0.0 to 21.0 Vol-% | 100% Relative Humidity
Accuracy |  | ± 0.15% of set point |  |  |  | ± 2% of set point | ± 0.05% of set point
Resolution |  | 0.01° |  |  |  | 0.01% vol | 0.01% vol
Dimensions (W x H x D mm) |  | 313 x 85.5 x 301 | 160 x 22 x 135 | 132 x 205 x 18 |  | 313 x 128 x 301 | 313 x 85.5 x 301 | 104 mm diameter, 124 mm height
Weight |  | ~5.4 kg |  |  |  | ~5.7 kg | ~5.7 kg | ~1.5kg
Method |  | 4 channel Direct to component and Gas Heating |  |  |  | Controlled release of CO2 Supply | Controlled release of N2 supply to displace O2 | Bubble the Gas flow through heated water to introduce humidity
Features |  | Supports heating of microscope objective | Supports Standard Slides as well as Petri dishes | Homogeneous Gas Distribution |  | Requires min 95% Concentrated pressurized CO2 supply @ 1-2 bar | Requires min 99% Concentrated pressurized N2 supply @ 1-2 bar | Accepts 250ml and 500ml humidification bottle
 |  | Supports software to log parameters during operation | 4 Levelling screws | Non Hermetic Seal, Continuous displacement venting |  |  |  | Heated via Temp Module
 |  |  | 46x21 mm observation opening | Heated via Temp Module
 |  |  | Heated via Temp Module
 |  |  | Supports perfusion experiments using 2 ports for tubes
General Working
 | Ibidi Silver Line Incubator
 |  | Heating System Slide/Dish – Silver Line | Heated Lid (for Slide/Dish System) | Heated Plate (for Slide/Dish System) |  | Gas Incubation System, CO2 – Silver Line | Gas Incubation System, CO2 / O2 – Silver Line | Humidifying tower
Range |  |  | Ambient + 5°C to 50°C (minimum of 18°C) | Ambient + 5°C to 46°C (minimum of 18°C) |  | 0 to 15% vol | (CO2 specs the same) (O2: 0.5 to 21%) | 20 to 99% (lower bound dependent on environment and gas supply
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

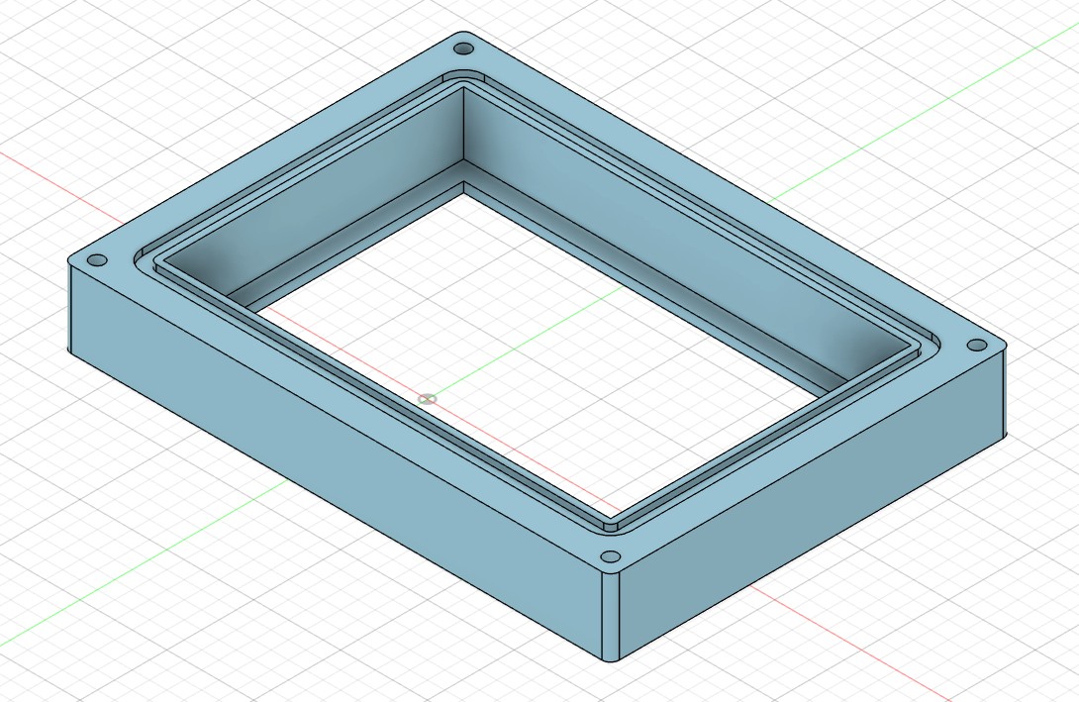
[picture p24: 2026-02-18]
Latex Report/Latex Report/Figures/Design1_Base.jpg

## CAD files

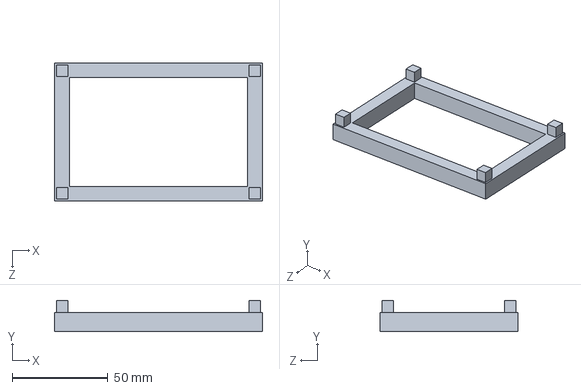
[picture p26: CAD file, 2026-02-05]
CAD Files/greiner_coverglass_gasket_holder_teco.SLDPRT
108.4 x 16.3 x 72.0 mm

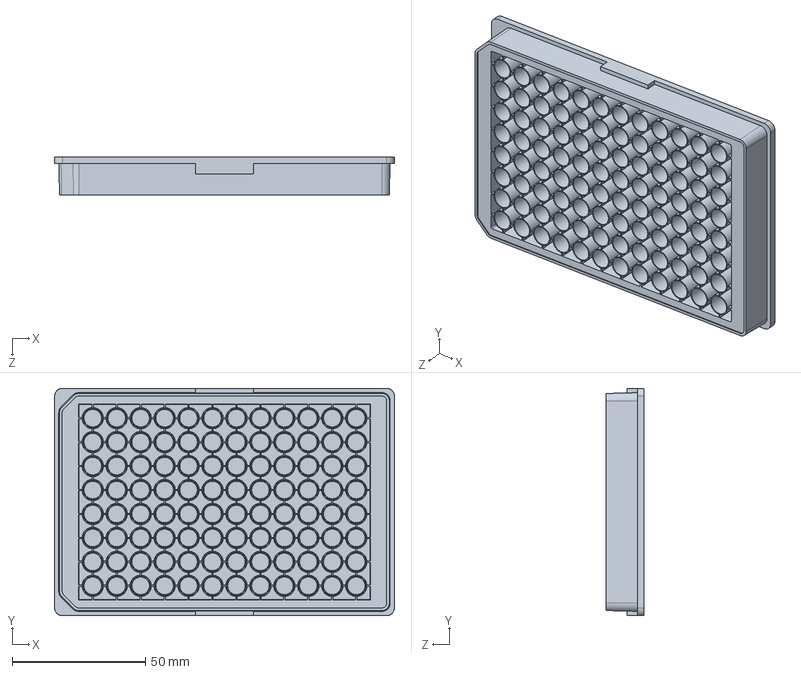
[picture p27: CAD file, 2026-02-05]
CAD Files/GREINER 96 WELL PLATE CELLSTAR.SLDPRT
127.8 x 85.5 x 14.4 mm

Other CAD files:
CAD Files/96well-PCR.f3d
CAD Files/Design V1/Chamber Base.f3d
CAD Files/Design V1/Chamber Lid (Assembly).f3z
CAD Files/Design V1/Chamber Lid.f3d
CAD Files/Design V2/Base V2.1.f3d
CAD Files/Design V2/Design_2_Assembly.f3z
CAD Files/Design V2/Lid V2 (Gasket).f3d
CAD Files/Design V2/Lid V2 (O-Ring).f3d
CAD Files/Design V3/Base V3.0.f3d
CAD Files/Design V3/Base V3.3.f3d
CAD Files/Design V3/Base V3.4.f3d
CAD Files/Design V3/Container V3.0 (Assembly).f3z
CAD Files/Design V3/Container V3.3 (Assembly).f3z
CAD Files/Design V3/Container V3.4 (Assembly).f3z
CAD Files/Design V3/Lid V3.0.f3d
CAD Files/Design V3/Lid V3.3.f3d
CAD Files/Design V3/Lid V3.4.f3d
CAD Files/GREINER 96 WELL PLATE (Downloaded Model).f3d
CAD Files/GREINER 96 WELL PLATE LID (Assembly).f3z
CAD Files/GREINER 96 WELL PLATE LID (Created).f3d

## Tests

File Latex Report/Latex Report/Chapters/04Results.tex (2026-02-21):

% ----------------------------------------------------
% Results and Discussion
% ----------------------------------------------------
\documentclass[class=report,11pt,crop=false]{standalone}
\input{../Style/ChapterStyle.tex}
\begin{document}
% ----------------------------------------------------
\chapter{Feasibility Discussion} \label{ch:results}
\vspace{-1cm}
% ----------------------------------------------------
With the final design shown in \autoref{ch:design}, it can be seen that it is possible to achieve sufficient containment capabilities for the purpose of containing cell cultures intended for BSL-3 Laboratories.

The use of an o-ring to seal the lid to the base would provide adequate containment as this is a common practice used in ingress protection(IP) techniques. The IP rating \cite{IngressProtectionIP} is a rating that is used to determine the protection from water and dust ingress for a product. The IP rating that best applies to this design is that illustrated by the IP68 requirements, which state the a device should be capable of handling full submersion in liquids without any ingress. This would provide sufficient containment for contagious cell cultures and thus would be suitable for a BSL-3 laboratory. 

IP68 containers are commonly made with the use of o-rings, as they provide complete seals whilst under pressure, and whilst still allowing easy access to the container. One potential issue is that the bio-containment chamber needs to be compatible with typical sterilisation techniques, including the autoclave and chemical disinfectants. Most o-rings are not capable of surviving the harsh conditions present in an autoclave, and so consideration must be taken to ensure that the  o-ring material is compatible with these conditions. One such material that is commonly used in medical laboratories is Silicone, which according to the Parker handbook \cite[73]{ORingHandbook}, is resistant to temperatures up to 210\degree C.

The use of a silicon based gasket present on the bottom of the base, which is used to seal the multi-well plate frame to the chamber, in conjunction with the o-ring present on the lid, would ensure that interior of the chamber is sufficiently sealed to prevent contamination. 

Material choice for the frame needs to be taken into consideration, since the chamber needs to withstand the serialisation and disinfection standards mentioned above. High temperature and pressure steam used in autoclaves promotes corrosion in certain metals, and so a corrosion resistant metal needs to be used to avoid damage. Additionally, the harsh chemicals used by disinfectants, such as bleach which acts as an oxidiser and so can easily corrode and deteriorate materials.

The use of screws to secure the lid and multi-well plate does introduce some difficulty with using the chamber, however this mechanism ensures that once the lid is properly fastened to the base, the container will remained sealed and will not potentially open during the experiments.

Overall this conceptual design shows strong evidence to suggest that a fully sealed bio-containment chamber can be made using available materials and manufacturing techniques and allow for the safe containment of potentially hazardous cell cultures that are handled in a BSL-3 laboratory. The containment chamber can be improved upon to allow for thermal control, this would be the first step into designing an incubation chamber that could be used in lab experiments.
% ----------------------------------------------------
\ifstandalone
\bibliography{../Bibliography/References.bib}
\fi
\end{document}
% ----------------------------------------------------

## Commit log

2026-02-02 Initial commit adding latex, word, excel and powerpoint documents.
    [Spec_Comparison.xlsx]
2026-02-02 Added CAD Files for DesignV1 and DesignV2
    [96well-PCR.f3d, Base V2.1.f3d, Chamber Base.f3d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]
2026-02-02 Added Research material: Instruction Manuals for commercial solutions
2026-02-04 Edited Research section. Completed first draft of Feasibility section for Zeis and Ibidi solutions.
    [Spec_Comparison.xlsx]
2026-02-05 Found CAD model for Greiner 96 well plate. Created Model for 96 Well Plate. Created assembly of parts
    [GREINER 96 WELL PLATE (Downloaded Model).f3d, GREINER 96 WELL PLATE LID (Assembly).f3z, GREINER 96 WELL PLATE LID (Created).f3d]
2026-02-05 Modified Design 2 Assembly to have newer MW Plate Model
    [Design_2_Assembly.f3z]
2026-02-05 Added Raw Multi-Well Model. Updated Multi-Well Plate Model. Updated Design V2. Created Design V3.
    [Base V2.1.f3d, Base V3.0.f3d, Container V3.0 (Assembly).f3z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]
2026-02-06 Design 3.3 has increased space inside chamber. Base of multiwell plate sits in sealing groove of base. holes for screw modified to allow flush seating. Lid now has standoffs to press plate into base.
    [Base V3.3.f3d, Container V3.3 (Assembly).f3z, GREINER 96 WELL PLATE LID (Assembly).f3z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]
2026-02-06 Created Chamber Design V3.4. Modified to work with threaded insert and countersunk screws.
    [Base V3.4.f3d, Container V3.4 (Assembly).f3z, Lid V3.4.f3d]
2026-02-18 Completed first draft of specs section, design v1. worked on presentation
    [Spec_Comparison.xlsx]
